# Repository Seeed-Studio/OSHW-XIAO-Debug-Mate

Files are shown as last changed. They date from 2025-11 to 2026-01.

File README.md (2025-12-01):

<p align="center">
  <h1 align="center">🔧 XIAO Debug Mate</h1>
  <p align="center">
    <strong>An Open-Source ESP32-S3 Multi-Tool for Embedded System Debugging</strong>
  </p>
  <p align="center">
    🐞 DAPLink Debugger | 📡 UART Monitor | ⚡ Power Profiler | 🖥️ Visual Feedback
  </p>
</p>

<p align="center">
  <a href="#-features">Features</a> •
  <a href="#-hardware">Hardware</a> •
  <a href="#-getting-started">Getting Started</a> •
  <a href="#-project-structure">Project Structure</a> •
  <a href="#-license">License</a>
</p>

<p align="center">
  <a href="https://www.seeedstudio.com/Seeed-Studio-XIAO-Debug-Mate-p-6588.html">
    
  </a>
  <a href="https://www.aliexpress.com/item/1005010448361665.html">
    
  </a>
  <a href="https://wiki.seeedstudio.com/getting_started_with_xiao_debug_mate/">
    
  </a>
</p>

<p align="center">
  
  
  
</p>

---

## 📖 Introduction

**Seeed Studio XIAO Debug Mate** is an open-source ESP32-S3 multi-tool that simplifies embedded system debugging with visual feedback. This all-in-one device features a standalone 2.01 inch TFT LCD display, LED status matrix, and native Seeed Studio XIAO support, delivering essential debugging functions: DAPLink chip-level debugging, built-in serial monitoring with UART passthrough, and accurate power consumption measurement. Plug-and-play design eliminates complex wiring for streamlined development.

## ✨ Features

### 🛠️ 3-in-1 Professional Development Tool

| Feature | Description |
|---|---|
| 🐞 **DAPLink-Compatible SWD Interface** | Powered by ESP32-S3 with full OpenOCD/PyOCD support, delivering professional-grade debugging capabilities. Set breakpoints, step through code, inspect memory, and access low-level hardware operations with precision. |
| 📡 **Intelligent Serial Monitor & UART Passthrough** | Monitor communications between your XIAO and the Debug Mate, or between the Debug Mate and external UART devices (Arduino, Raspberry Pi, Grove sensors). View real-time serial data on the onboard display or redirect to PC for detailed analysis. |
| ⚡ **Precision Power Profiling** | Track power consumption down to μA levels. Monitor voltage/current readings, ultra-low-power states, and consumption patterns with peak/valley identification. Factory-calibrated for maximum accuracy (±10% @ 1-10μA). |

### 🖥️ Standalone Visual Feedback System

Monitor key system metrics **without connecting to a PC**. The integrated 2.01" LCD screen displays real-time serial communications, power consumption readings, and UART data streams, while the programmable 36-LED matrix provides instant baud rate indicators. Perfect for on-site field testing, mobile development, and quick system power consumption checks.

### 🔌 Open-Source Platform with Universal Compatibility

Purpose-built for the **Seeed Studio XIAO ecosystem** with direct plug-and-play connection—any pre-soldered XIAO board connects instantly without tedious wiring. The thoughtfully designed pin headers and sockets transform the device into a specialized expansion breadboard for XIAO development. While optimized for XIAO, the open-source design extends compatibility to **any ARM Cortex-M microcontroller** via standard SWD and UART interfaces.

## 📋 Specifications

| Parameter | Description |
|---|---|
| **Processor** | Espressif ESP32-S3 |
| **Power Input** | USB-C 5V/1A |
| **Display** | 2.01 inch TFT LCD (240 × 296 resolution) |
| **LED** | 36-LED Matrix for Status Indication (Default: Baud Rate) |
| **User Input** | 1 × User Button/Boot Button, 1 × Scroll Wheel, 1 × Recessed Reset Button |
| **I/O Interface** | 14 × XIAO Standard Pins, 8 × Expansion Pins, 4 × SWD Debugging Pins, 1 × UART Grove Connector |
| **Product Size** | 100 × 56 × 20 mm |
| **Software** | Supports DAPLink for debugging |
| **Enclosure** | 3D-Printed in Black PLA |

## 🎯 Supported Target Boards

| Board | Interface | Status |
|---|---|---|
| 🟢 XIAO SAMD21 | SWD | ✅ Supported |
| 🟢 XIAO RA4M1 | SWD | ✅ Supported |
| 🟢 XIAO nRF52840 (Sense) | SWD | ✅ Supported |
| 🟢 XIAO RP2040 | SWD | ✅ Supported |
| 🟢 XIAO RP2350 | SWD | ✅ Supported |
| 🟢 XIAO MG24 (Sense) | SWD (OpenOCD) | ✅ Supported |

> ⚠️ **Note:** XIAO nRF54L15 and XIAO ESP32 series (C3/S3/C6) do **not** currently support debugging feature.

## 🚀 Getting Started

### ⚡ Quick Flash (Recommended for Users)

If you just want to use the XIAO Debug Mate, flash the pre-compiled firmware:

1. Install esptool: `pip install esptool`
2. Connect XIAO Debug Mate via USB-C
3. Enter download mode (hold BOOT, press RESET)
4. Run the flash script:

| OS | How to Run |
|----|---|
| 🍎 **macOS** | Open Terminal, navigate to `5_Release_firmware/`, run `./flash.sh` |
| 🐧 **Linux** | Open Terminal, navigate to `5_Release_firmware/`, run `./flash.sh` |
| 🪟 **Windows** | Double-click `flash.bat` |

```bash
# macOS / Linux
cd 5_Release_firmware
./flash.sh
```

> The script automatically detects and flashes the latest firmware version!

---

### 🛠️ Build from Source (For Developers)

#### Prerequisites

- **Arduino IDE** 2.x or later
- **ESP32 Board Support** (version 3.1.3, installed via Arduino Board Manager)
- **USB-C Cable** for programming

#### Quick Start

1️⃣ **Clone the Repository**
```bash
git clone https://github.com/Seeed-Studio/OSHW-XIAO-Debug-Mate.git
cd OSHW-XIAO-Debug-Mate
```

2️⃣ **Install Libraries**

Copy all libraries from `1_Libraries/` and the firmware library to your Arduino libraries folder:
```bash
# macOS / Linux
cp -r 1_Libraries/* ~/Documents/Arduino/libraries/
cp -r 0_Firmware ~/Documents/Arduino/libraries/Seeed_Debugger

# Windows
xcopy /E /I 1_Libraries\* "%USERPROFILE%\Documents\Arduino\libraries\"
xcopy /E /I 0_Firmware "%USERPROFILE%\Documents\Arduino\libraries\Seeed_Debugger"
```

> ⚠️ **Important:** The firmware must be installed as an Arduino library to compile correctly.

3️⃣ **Modify ESP32 Core Files**

> ⚠️ **Important:** You must modify the ESP32 Arduino core files to disable default USB initialization, otherwise TinyUSB will conflict with the default USB stack.

**Locate the ESP32 core files:**

| OS | Path |
|----|---|
| 🍎 **macOS** | `~/Library/Arduino15/packages/esp32/hardware/esp32/3.1.3/cores/esp32/` |
| 🪟 **Windows** | `%LOCALAPPDATA%\Arduino15\packages\esp32\hardware\esp32\3.1.3\cores\esp32\` |
| 🐧 **Linux** | `~/.arduino15/packages/esp32/hardware/esp32/3.1.3/cores/esp32/` |

**Modify the following 3 files:**

**File 1: `USB.cpp`** (around line 352)
```cpp
// Before:
ESPUSB USB;

// After:
// ESPUSB USB;
```

**File 2: `USB.h`** (around line 119)
```cpp
// Before:
extern ESPUSB USB;

// After:
// extern ESPUSB USB;
```

**File 3: `main.cpp`** (around lines 98 and 101)
```cpp
// Before:
#if ARDUINO_USB_DFU_ON_BOOT && !ARDUINO_USB_MODE
    USB.enableDFU();
#endif
#if ARDUINO_USB_ON_BOOT && !ARDUINO_USB_MODE
    USB.begin();
#endif

// After:
#if ARDUINO_USB_DFU_ON_BOOT && !ARDUINO_USB_MODE
    // USB.enableDFU();
#endif
#if ARDUINO_USB_ON_BOOT && !ARDUINO_USB_MODE
    // USB.begin();
#endif
```

4️⃣ **Configure Arduino IDE**

Set the following options in Arduino IDE:
- **Board**: "XIAO ESP32S3"
- **Partition Scheme**: "Maximum APP (7.9MB APP No OTA/No FS)"
- **PSRAM**: "OPI PSRAM"
- **USB Mode**: "USB-OTG (TinyUSB)"

5️⃣ **Upload Firmware**

- Go to **File → Examples → Seeed All-in-one Debugger → main**
- Or open `0_Firmware/examples/main/main.ino` directly
- Click **Upload**

## 📁 Project Structure

```
OSHW-XIAO-Debug-Mate/
├── 📂 0_Firmware/           # 🔧 Main firmware source code
│   ├── examples/            # Arduino sketch entry point
│   └── src/                 # Core library source files
│
├── 📂 1_Libraries/          # 📚 Required Arduino libraries
│   ├── Adafruit_BusIO/      # I2C/SPI communication
│   ├── Adafruit_INA228/     # Power monitoring sensor
│   ├── Adafruit_TinyUSB/    # USB device support
│   ├── lvgl_debug_mate/     # LVGL graphics library
│   ├── Seeed_Arduino_DAPLink/  # DAPLink implementation
│   ├── TFT_eSPI_Debug_Mate/ # TFT display driver
│   └── ...                  # Other supporting libraries
│
├── 📂 2_DAPLink_Package/    # 🎯 DAPLink tools and examples
│   ├── examples/            # Pre-compiled test binaries
│   ├── target/              # OpenOCD target configurations
│   └── XIAO_MG24_*/         # OpenOCD for MG24 debugging
│
├── 📂 3_Product_housing/    # 🏠 3D printable enclosure
│   └── *.stp, *.3mf         # CAD files for housing
│
├── 📂 4_Hardware/           # ⚡ Hardware documentation
│   └── *.pdf                # Schematic diagrams
│
└── 📂 5_Release_firmware/   # 📦 Pre-compiled firmware binaries
    ├── firmware-v*.bin      # Ready-to-flash firmware
    ├── flash.sh             # One-click flash (macOS/Linux)
    └── flash.bat            # One-click flash (Windows)
```

## 🖥️ User Interface

The XIAO Debug Mate features an intuitive menu system:

```
┌─────────────────────────────────┐
│         🏠 Main Menu            │
├─────────────────────────────────┤
│  📡  Function UART              │
│  ⚡  Function Power             │
└─────────────────────────────────┘
```

### Navigation
- **🔄 Scroll Wheel** - Navigate menu items
- **👆 Press** - Select/Confirm
- **👆 Long Press** - Back/Exit

## ⚙️ Configuration

### Baud Rate Options
The UART bridge supports multiple baud rates:
- 9600, 19200, 38400, 57600, 115200, 230400, 460800, 921600

### Power Monitoring
- **Accuracy**: ±10% @ 1-10μA (factory-calibrated)
- **Current Range**: μA to mA level precision
- **Features**: Peak/valley identification, real-time monitoring

## 🔗 Resources

- 🛒 [**Buy at Seeed Studio**](https://www.seeedstudio.com/Seeed-Studio-XIAO-Debug-Mate-p-6588.html)
- 🛒 [**Buy at AliExpress**](https://www.aliexpress.com/item/1005010448361665.html)
- 📖 [**Wiki Documentation**](https://wiki.seeedstudio.com/getting_started_with_xiao_debug_mate/)
- 💻 [**GitHub Repository**](https://github.com/Seeed-Studio/OSHW-XIAO-Debug-Mate)

## 🤝 Contributing

We welcome contributions! Please feel free to:

- 🐛 Report bugs
- 💡 Suggest new features
- 🔧 Submit pull requests
- 📖 Improve documentation

## 📄 License

This project is open-source hardware (OSHW). See individual library directories for their specific licenses.

## 🙏 Acknowledgments
This product started with a simple GitHub discussion back in July 2024, where one of our XIAO Core users [rei-vilo opened Discussion #20 in our XIAO Open Roadmap](https://github.com/orgs/Seeed-Studio/discussions/20) with an observation that resonated with many developers: “A programmer-debugger probe is a very useful and ‘must have’ tool for embedded system development. Today, there is no affordable offer.” Then we started the journey of creating this device together with many other community members who contributed a lot of input. Thank you to everyone who contributed ideas and feedback throughout this journey. A special big shout-out to [rei-vilo](https://github.com/rei-vilo), [Chris](https://github.com/CWGwaltney), PJ, Hendra, Ernesto, [Benjamin](https://github.com/kartben), [Pete](https://github.com/petejohanson), NitekryDPaul for insightful feedback during v0.1 testing.

- **Seeed Studio** - Hardware design and development
- **LVGL** - Graphics library
- **Adafruit** - Various Arduino libraries
- **ARM** - CMSIS-DAP protocol
- **[啊猫啊狗晒太阳](https://space.bilibili.com/1155738723)** - [Design inspiration](https://www.bilibili.com/video/BV1Sc411273Y/) for the LED matrix

---

<p align="center">
  Made with ❤️ by <a href="https://www.seeedstudio.com">Seeed Studio</a>
</p>

<p align="center">
  <sub>🌟 Star us on GitHub — it motivates us a lot!</sub>
</p>

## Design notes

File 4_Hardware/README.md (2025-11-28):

# ⚡ Hardware Documentation

This directory contains the hardware design documentation for the XIAO Debug Mate.

## 📁 Files Included

| File | Description |
|---|---|
| `Seeed_Studio_XIAO_Debug_Mate_V1.0_SCH_20250926.pdf` | Complete schematic diagram |

## 📋 Hardware Specifications

### Main Controller

| Parameter | Value |
|---|---|
| Module | Seeed Studio XIAO ESP32-S3 |
| MCU | ESP32-S3 (Xtensa LX7 dual-core) |
| Clock Speed | 240 MHz |
| Flash | 8 MB |
| PSRAM | 8 MB (OPI) |
| USB | Native USB OTG |

### Display

| Parameter | Value |
|---|---|
| Type | TFT LCD |
| Controller | ST7789 |
| Resolution | 240 × 320 pixels |
| Size | 2.0 inches |
| Interface | SPI |
| Color Depth | 16-bit (RGB565) |

### Power Monitor

| Parameter | Value |
|---|---|
| IC | Texas Instruments INA228 |
| Interface | I2C (Address: 0x43) |
| Voltage Range | 0-85V |
| Current Sense | External shunt |
| Shunt Resistor | 68mΩ |
| Max Current | 1A |
| Resolution | 20-bit ADC |

### Storage

| Parameter | Value |
|---|---|
| Type | I2C EEPROM |
| Interface | I2C (Address: 0x50) |
| Capacity | Varies by model |
| Purpose | Configuration storage |

### User Interface

| Component | Description |
|---|---|
| Rotary Encoder | Navigation input with push button |
| Status LEDs | Shift register controlled RGB LEDs |
| Boot Button | GPIO0 for mode selection |

## 🔌 Pinout Reference

### XIAO ESP32-S3 Pin Assignments

```
                    ┌─────────────┐
                    │  XIAO       │
                    │  ESP32-S3   │
         ┌──────────┤             ├──────────┐
         │          │             │          │
    D0 ──┤ GPIO1    │             │ GPIO44 ├── TX
    D1 ──┤ GPIO2    │             │ GPIO43 ├── RX
    D2 ──┤ GPIO3    │             │ GPIO7  ├── LED_CLK
    D3 ──┤ GPIO4    │             │ GPIO8  ├── LED_LATCH
    D4 ──┤ GPIO5    │             │ GPIO9  ├── LED_DATA
    D5 ──┤ GPIO6    │             │ GPIO17 ├── ENC_B
         │          │             │ GPIO18 ├── ENC_A
         │          │             │ GPIO48 ├── UART_SW
         │          │             │ GPIO0  ├── BOOT_BTN
         │          │             │ GPIO15 ├── MOS2
         │          │             │ GPIO16 ├── MOS1
         └──────────┤             ├──────────┘
                    │   USB-C     │
                    └─────────────┘
```

### I2C Bus Connections

| Device | SDA Pin | SCL Pin | Address | Speed |
|---|---|---|---|---|
| INA228 | GPIO4 | GPIO3 | 0x43 | 100kHz |
| EEPROM | GPIO1 | GPIO2 | 0x50 | 100kHz |

### LED Shift Register

| Pin | Function |
|-----|---|
| GPIO9 | Serial Data |
| GPIO7 | Clock |
| GPIO8 | Latch |

### Rotary Encoder

| Pin | Function |
|-----|---|
| GPIO18 | Channel A |
| GPIO17 | Channel B |
| GPIO0 | Push Button (shared with BOOT) |

### UART Bridge

| Pin | Function |
|-----|---|
| Serial0 RX | Target TX |
| Serial0 TX | Target RX |
| GPIO48 | UART Switch Control |

## 📊 Block Diagram

```
┌─────────────────────────────────────────────────────────────────┐
│                      XIAO Debug Mate                            │
│                                                                 │
│  ┌─────────────┐     ┌─────────────┐     ┌─────────────┐       │
│  │   XIAO      │     │   ST7789    │     │   INA228    │       │
│  │  ESP32-S3   │────▶│   Display   │     │  Power Mon  │       │
│  │             │     │  240×320    │     │             │       │
│  │   USB-OTG   │     └─────────────┘     └──────┬──────┘       │
│  └──────┬──────┘                                │              │
│         │         ┌─────────────┐               │              │
│         │         │   I2C       │◀──────────────┘              │
│         │         │   EEPROM    │                              │
│         │         └─────────────┘                              │
│         │                                                       │
│         │         ┌─────────────┐     ┌─────────────┐          │
│         │         │   Shift     │     │   Rotary    │          │
│         └────────▶│   Register  │     │   Encoder   │          │
│                   │   (LEDs)    │     │             │          │
│                   └─────────────┘     └─────────────┘          │
│                                                                 │
│  ┌─────────────────────────────────────────────────────────┐   │
│  │                   Debug Connector                        │   │
│  │   SWDIO  SWCLK  GND  3V3  RST  TX  RX                   │   │
│  └─────────────────────────────────────────────────────────┘   │
└─────────────────────────────────────────────────────────────────┘
```

## ⚡ Power Architecture

```
USB 5V ──┬──▶ XIAO 3.3V LDO ──▶ Internal Logic
         │
         └──▶ Power Output ──▶ Target Device (optional)
                    │
                    └──▶ INA228 Current Sense ──▶ Measurement
```

### Power Specifications

| Parameter | Min | Typical | Max | Unit |
|---|-----|---|-----|---|
| Input Voltage (USB) | 4.5 | 5.0 | 5.5 | V |
| Operating Current | - | 100 | 250 | mA |
| Target Power Output | - | 3.3 | - | V |
| Target Current Limit | - | - | 500 | mA |

## 🔧 Debug Interface

### SWD Connector Pinout

| Pin | Signal | Description |
|-----|---|---|
| 1 | VCC | Target power (3.3V) |
| 2 | SWDIO | Serial Wire Data |
| 3 | SWCLK | Serial Wire Clock |
| 4 | GND | Ground |
| 5 | RST | Target Reset |

### UART Header Pinout

| Pin | Signal | Description |
|-----|---|---|
| 1 | TX | Transmit (to target RX) |
| 2 | RX | Receive (from target TX) |
| 3 | GND | Ground |

## 📐 Mechanical Dimensions

| Parameter | Value |
|---|---|
| PCB Length | ~90 mm |
| PCB Width | ~50 mm |
| Overall Height | ~25 mm (with housing) |

## 🛠️ Design Files

The schematic PDF provides:
- Complete circuit topology
- Component values and part numbers
- Net names for debugging
- Power distribution network

### Reading the Schematic

1. **Power Section** - USB input, regulators, power distribution
2. **MCU Section** - XIAO ESP32-S3 connections
3. **Display Section** - TFT interface and backlight
4. **Sensor Section** - INA228 and EEPROM
5. **Interface Section** - Debug connector and UART
6. **LED Section** - Shift register and status LEDs

## ⚠️ Design Considerations

### EMI/EMC
- Keep SWD traces short and matched
- Use ground plane under high-speed signals
- Add ferrite beads on power inputs

### Signal Integrity
- Maintain controlled impedance for SPI signals
- Use series termination resistors where needed
- Minimize crosstalk between analog and digital

### Thermal
- Ensure adequate copper pour for heat dissipation
- Consider airflow in enclosure design
- Monitor operating temperature during extended use

## 📚 References

- [ESP32-S3 Technical Reference Manual](https://www.espressif.com/sites/default/files/documentation/esp32-s3_technical_reference_manual_en.pdf)
- [INA228 Datasheet](https://www.ti.com/lit/ds/symlink/ina228.pdf)
- [ST7789 Datasheet](https://www.crystalfontz.com/controllers/Sitronix/ST7789V/)
- [CMSIS-DAP Specification](https://arm-software.github.io/CMSIS_5/DAP/html/index.html)

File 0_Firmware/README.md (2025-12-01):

# 🔧 XIAO Debug Mate Firmware

This directory contains the main firmware source code for the XIAO Debug Mate. The firmware is structured as an **Arduino Library** and must be installed in your Arduino libraries folder to use.

## 📦 Installation

### Method 1: Copy to Arduino Libraries (Recommended)

Copy the entire `0_Firmware` folder to your Arduino libraries directory and rename it:

```bash
# macOS
cp -r 0_Firmware ~/Documents/Arduino/libraries/Seeed_Debugger

# Windows
xcopy /E /I 0_Firmware "%USERPROFILE%\Documents\Arduino\libraries\Seeed_Debugger"

# Linux
cp -r 0_Firmware ~/Arduino/libraries/Seeed_Debugger
```

### Method 2: Symbolic Link (For Development)

Create a symbolic link if you want to develop and modify the firmware:

```bash
# macOS / Linux
ln -s "$(pwd)/0_Firmware" ~/Documents/Arduino/libraries/Seeed_Debugger

# Windows (Run as Administrator)
mklink /D "%USERPROFILE%\Documents\Arduino\libraries\Seeed_Debugger" "%cd%\0_Firmware"
```

## 📁 Directory Structure

```
0_Firmware/
├── examples/
│   └── main/
│       └── main.ino      # Main Arduino sketch entry point
├── src/                  # Core library source files
│   ├── DapLink.*         # DAPLink debugger implementation
│   ├── StateMachine.*    # State machine framework
│   ├── StateManager.*    # State management
│   ├── MenuStates.*      # Main menu UI states
│   ├── FunctionUartState.*   # UART bridge function
│   ├── FunctionBaudState.*   # Baud rate configuration
│   ├── FunctionPowerState.*  # Power monitoring function
│   ├── InputTask.*       # Scroll wheel and button input handling
│   ├── DisplayContext.*  # Display management
│   ├── LvglStyle.*       # LVGL UI styling
│   ├── Tool.*            # Utility functions
│   ├── frame.*           # Boot animation frames
│   └── ...
├── library.properties    # Arduino library metadata
└── keywords.txt          # Syntax highlighting keywords
```

## 🚀 Getting Started

### Prerequisites

1. **Arduino IDE 2.x** or later
2. **ESP32 Board Package** version 3.1.3 installed via Board Manager
3. All libraries from `1_Libraries/` installed (see [1_Libraries/README.md](../1_Libraries/README.md))
4. This firmware library installed (see Installation above)

### Step 1: Install Required Libraries

Copy all libraries from `1_Libraries/` to your Arduino libraries folder:

```bash
# macOS
cp -r ../1_Libraries/* ~/Documents/Arduino/libraries/

# Windows
xcopy /E /I ..\1_Libraries\* "%USERPROFILE%\Documents\Arduino\libraries\"

# Linux
cp -r ../1_Libraries/* ~/Arduino/libraries/
```

### Step 2: Modify ESP32 Core Files

> ⚠️ **Important:** You must modify the ESP32 Arduino core files to disable default USB initialization, otherwise TinyUSB will conflict with the default USB stack.

**Locate the ESP32 core files:**

| OS | Path |
|----|---|
| 🍎 **macOS** | `~/Library/Arduino15/packages/esp32/hardware/esp32/3.1.3/cores/esp32/` |
| 🪟 **Windows** | `%LOCALAPPDATA%\Arduino15\packages\esp32\hardware\esp32\3.1.3\cores\esp32\` |
| 🐧 **Linux** | `~/.arduino15/packages/esp32/hardware/esp32/3.1.3/cores/esp32/` |

**Modify the following 3 files:**

#### File 1: `USB.cpp` (around line 352)
```cpp
// Before:
ESPUSB USB;

// After:
// ESPUSB USB;
```

#### File 2: `USB.h` (around line 119)
```cpp
// Before:
extern ESPUSB USB;

// After:
// extern ESPUSB USB;
```

#### File 3: `main.cpp` (around lines 98 and 101)
```cpp
// Before:
#if ARDUINO_USB_DFU_ON_BOOT && !ARDUINO_USB_MODE
    USB.enableDFU();
#endif
#if ARDUINO_USB_ON_BOOT && !ARDUINO_USB_MODE
    USB.begin();
#endif

// After:
#if ARDUINO_USB_DFU_ON_BOOT && !ARDUINO_USB_MODE
    // USB.enableDFU();
#endif
#if ARDUINO_USB_ON_BOOT && !ARDUINO_USB_MODE
    // USB.begin();
#endif
```

### Step 3: Configure Arduino IDE

Configure the following settings in Arduino IDE:

| Setting | Value |
|---|---|
| **Board** | XIAO ESP32S3 |
| **Partition Scheme** | Maximum APP (7.9MB APP No OTA/No FS) |
| **PSRAM** | OPI PSRAM |
| **USB Mode** | USB-OTG (TinyUSB) |

### Step 4: Open and Upload

1. In Arduino IDE, go to **File → Examples → Seeed All-in-one Debugger → main**
2. Or open `examples/main/main.ino` directly
3. Select the correct port (your XIAO Debug Mate)
4. Click **Upload**

> 💡 **Tip:** If the device is not detected, enter Boot Mode by holding BOOT button while pressing RESET.

## 🏗️ Architecture

The firmware uses a **State Machine** architecture for managing different operational modes:

```
┌─────────────────┐
│   Main Menu     │◄────────────────┐
└────────┬────────┘                 │
         │                          │
    ┌────┴────┐                     │
    ▼         ▼                     │
┌───────┐ ┌───────┐                 │
│ UART  │ │ Power │──── Back ───────┤
│ Mode  │ │ Mode  │                 │
└───┬───┘ └───────┘                 │
    │                               │
    ▼                               │
┌───────┐                           │
│ Baud  │──── Back ─────────────────┘
│ Rate  │
└───────┘
```

## 📦 Core Components

### State Machine (`StateMachine.*`)
- Manages application states and transitions
- Handles state initialization and cleanup
- Provides error state fallback

### Input Task (`InputTask.*`)
- Handles scroll wheel rotation
- Debounces button presses
- Detects long press events
- Sends events to state machine via FreeRTOS queue

### Display Context (`DisplayContext.*`)
- Manages LVGL display operations
- Controls 36-LED status matrix
- Interfaces with INA228 power monitor

### DAPLink (`DapLink.*`)
- Implements CMSIS-DAP protocol
- Provides SWD debugging interface
- Handles USB HID communication

## 🔧 Key Functions

### Main Menu Functions

| Function | Description |
|---|---|
| **UART Mode** | Serial monitor & UART passthrough |
| **Power Mode** | Precision power profiling (μA level) |

### UART Mode Features
- Configurable baud rate (9600 - 921600)
- Real-time TX/RX data visualization on display
- 36-LED matrix shows current baud rate

### Power Mode Features
- Real-time voltage/current display
- μA level precision (factory-calibrated)
- Peak/valley identification

## ⚙️ Configuration

### Hardware Pins (defined in `Global.h`)

```cpp
#define BOOT_BTN 0
#define ENCODER_PINA 18
#define ENCODER_PINB 17
#define UART_SWITCH 48
#define LED_DATA 9
#define LED_CLOCK 7
#define LED_LATCH 8
```

### Display Settings

```cpp
#define TFT_HOR_RES   240
#define TFT_VER_RES   296
#define TFT_ROTATION  LV_DISPLAY_ROTATION_90
```

## 🐛 Debugging

Serial debug output is available at the configured baud rate:

```cpp
ShowSerial.begin(FunctionBaudState::m_baudRate);
```

Debug messages can be viewed via the Arduino Serial Monitor.

## 📝 Adding New States

To add a new function state:

1. Create new state files (e.g., `NewFunctionState.h/.cpp`) in the `src/` folder
2. Inherit from `State` base class
3. Implement required virtual methods:
   - `enter()` - Called when entering state
   - `exit()` - Called when leaving state
   - `handleEvent()` - Process user input events
4. Register state in `main.ino`:
   ```cpp
   NewFunctionState* newState = new NewFunctionState();
   stateManager->registerState(newState);
   ```
5. Add menu item in MainMenuState

## ⚠️ Troubleshooting

### Library Not Found

If Arduino IDE can't find the library:
1. Make sure the folder is named correctly in the libraries directory
2. Restart Arduino IDE after installing
3. Check **File → Examples** to see if "Seeed All-in-one Debugger" appears

### Compilation Errors

1. Ensure all dependencies from `1_Libraries/` are installed
2. Check that ESP32 board package version is 3.1.3
3. Verify Arduino IDE settings match the table above
4. **If you see USB-related errors:** Make sure you've modified the ESP32 core files (see Step 2)

### USB Conflict / TinyUSB Not Working

If DAPLink or USB functionality doesn't work:
1. Verify you've commented out the USB initialization in the ESP32 core files
2. Make sure you modified all 3 files: `USB.cpp`, `USB.h`, and `main.cpp`
3. Restart Arduino IDE after modifying core files

### Upload Failed

1. Enter Boot Mode: Hold BOOT → Press RESET → Release BOOT
2. Select the correct COM port
3. Try a different USB cable (use data cable, not charge-only)

## 📄 License

Part of the XIAO Debug Mate open-source hardware project by Seeed Studio.

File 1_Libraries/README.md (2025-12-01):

# 📚 Required Libraries

This directory contains all the Arduino libraries required for the XIAO Debug Mate firmware.

## 📦 Installation

### Option 1: Use Pre-packaged Libraries (Recommended)

Copy all contents of this directory to your Arduino libraries folder:

```bash
# macOS
cp -r * ~/Documents/Arduino/libraries/

# Windows
xcopy /E /I * "%USERPROFILE%\Documents\Arduino\libraries\"

# Linux
cp -r * ~/Arduino/libraries/
```

### Option 2: Install from Source

#### Step 1: Install from Arduino Library Manager

Open Arduino IDE → **Sketch → Include Library → Manage Libraries**, then install:

| Library | Recommended Version |
|---|---|
| **Adafruit INA228 Library** | 2.0.1 |
| **Adafruit TinyUSB Library** | 3.4.4 |

#### Step 2: Clone Custom Libraries

These libraries require specific branches. Open terminal and run:

```bash
# Go to the library directory
cd ~/Documents/Arduino/libraries

# DAPLink (custom ESP32-S3 branch)
git clone --depth 1 https://github.com/Lesords/Seeed_Arduino_DAPLink.git -b feat/ESP32S3

# TFT (custom ST7789-EVT branch)
git clone --depth 1 https://github.com/Lesords/TFT_eSPI.git -b feat/ST7789-EVT

# LVGL (custom Debugger branch)
git clone --depth 1 https://github.com/Lesords/lvgl.git -b feat/Debugger
```

## 📋 Library Overview

| Library | Version / Branch | Source | Description |
|---|---|---|---|
| **Seeed_Arduino_DAPLink** | `feat/ESP32S3` | [Lesords/Seeed_Arduino_DAPLink](https://github.com/Lesords/Seeed_Arduino_DAPLink/tree/feat/ESP32S3) | CMSIS-DAP debugger (ESP32-S3 fork) |
| **TFT_eSPI** | `feat/ST7789-EVT` | [Lesords/TFT_eSPI](https://github.com/Lesords/TFT_eSPI/tree/feat/ST7789-EVT) | TFT display driver (custom fork) |
| **lvgl** | `feat/Debugger` | [Lesords/lvgl](https://github.com/Lesords/lvgl/tree/feat/Debugger) | LVGL graphics library (custom fork) |
| **Adafruit_INA228** | 2.0.1 | [adafruit/Adafruit_INA228](https://github.com/adafruit/Adafruit_INA228) | Power monitor driver |
| **Adafruit_TinyUSB** | 3.4.4 | [adafruit/Adafruit_TinyUSB_Arduino](https://github.com/adafruit/Adafruit_TinyUSB_Arduino) | USB device stack |
| **Adafruit_BusIO** | 1.17.4 | [adafruit/Adafruit_BusIO](https://github.com/adafruit/Adafruit_BusIO) | I2C/SPI abstraction layer |
| **I2C_EEPROM** | 1.9.4 | [RobTillaart/I2C_EEPROM](https://github.com/RobTillaart/I2C_EEPROM) | I2C EEPROM library |
| **Adafruit_NeoPixel** | 1.3.3 | [adafruit/Adafruit_NeoPixel](https://github.com/adafruit/Adafruit_NeoPixel) | RGB LED driver |
| **Adafruit_SPIFlash** | 5.1.1 | [adafruit/Adafruit_SPIFlash](https://github.com/adafruit/Adafruit_SPIFlash) | SPI Flash support |
| **SdFat** | 2.3.54 | [adafruit/SdFat](https://github.com/adafruit/SdFat) | SD card FAT filesystem |
| **MIDI_Library** | 5.0.2 | [FortySevenEffects/arduino_midi_library](https://github.com/FortySevenEffects/arduino_midi_library) | MIDI communication |

## ⚠️ Important: Custom Library Branches

The following libraries **must** use specific custom branches to work with XIAO Debug Mate:

| Library | Required Branch | Why |
|---|---|-----|
| **Seeed_Arduino_DAPLink** | `feat/ESP32S3` | ESP32-S3 specific implementation |
| **TFT_eSPI** | `feat/ST7789-EVT` | Pre-configured for Debug Mate display |
| **lvgl** | `feat/Debugger` | Custom UI components and boot animation |

> ⚠️ Using the original/main branches will **not** work!

## 🔍 Library Details

### 🐞 Seeed_Arduino_DAPLink

Custom fork with ESP32-S3 support for CMSIS-DAP debugging.

**Branch:** `feat/ESP32S3`  
**Source:** https://github.com/Lesords/Seeed_Arduino_DAPLink

**Supported Protocols:**
- SWD (Serial Wire Debug)

**Supported Targets:**
- ARM Cortex-M0/M0+
- ARM Cortex-M3/M4
- ARM Cortex-M33

### 🖥️ TFT_eSPI

Custom fork optimized for the XIAO Debug Mate display.

**Branch:** `feat/ST7789-EVT`  
**Source:** https://github.com/Lesords/TFT_eSPI

**Features:**
- ST7789 driver support (240×296 resolution)
- Hardware SPI acceleration
- LVGL integration ready
- Pre-configured `User_Setup.h`

### 🎨 lvgl (LVGL Debug Mate)

LVGL (Light and Versatile Graphics Library) customized for Debug Mate.

**Branch:** `feat/Debugger`  
**Source:** https://github.com/Lesords/lvgl

**Features:**
- Animated boot screen
- Menu system widgets
- Power monitoring display
- Custom fonts and styles

**Configuration:** Settings in `lv_conf.h`

### ⚡ Adafruit_INA228

Driver for the INA228 high-precision power monitor IC.

**Version:** 2.0.1 (from Arduino Library Manager)  
**Source:** https://github.com/adafruit/Adafruit_INA228

**Capabilities:**
- Voltage measurement: 0-85V
- Current measurement (with external shunt)
- Power calculation
- Energy accumulation

**Debug Mate Config:**
```cpp
ina228.setShunt(0.068, 1.0);  // 68mΩ shunt, 1A max
ina228.setAveragingCount(INA228_COUNT_16);
```

### 🔌 Adafruit_TinyUSB

USB device stack enabling USB functionality.

**Version:** 3.4.4 (from Arduino Library Manager)  
**Source:** https://github.com/adafruit/Adafruit_TinyUSB_Arduino

**Features Used:**
- USB CDC (Serial)
- USB HID (for DAPLink)
- Composite USB device

### 💾 I2C_EEPROM

Library for reading/writing I2C EEPROM chips.

**Version:** 1.9.4  
**Source:** https://github.com/RobTillaart/I2C_EEPROM

**Usage:**
- Store user settings
- Persist baud rate configuration
- Save calibration data

## ⚙️ Configuration Files

### `lv_conf.h`

Main LVGL configuration file. Key settings:

```c
#define LV_COLOR_DEPTH 16
#define LV_MEM_SIZE (48 * 1024)
#define LV_USE_ANIMIMG 1
#define LV_FONT_MONTSERRAT_14 1
```

## 🛠️ Troubleshooting

### Library Not Found Error
Make sure all libraries are copied to the correct Arduino libraries folder.

### Compilation Errors
1. Ensure you're using the correct custom branches (not main/master)
2. Remove any duplicate libraries from your Arduino libraries folder
3. Restart Arduino IDE after installing libraries

### Display Not Working
Check that you're using `TFT_eSPI` from the `feat/ST7789-EVT` branch, not the standard library.

### DAPLink Not Working
Ensure you're using `Seeed_Arduino_DAPLink` from the `feat/ESP32S3` branch.

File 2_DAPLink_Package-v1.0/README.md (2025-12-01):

# 🎯 DAPLink Package v1.0

This directory contains pre-compiled example binaries, target configurations, and OpenOCD tools for debugging various XIAO boards with the XIAO Debug Mate.

## 📖 Documentation

For complete usage instructions, please refer to the official Wiki:

👉 **[DAPLink Debugger Wiki](https://wiki.seeedstudio.com/xiao_debug_mate_debug/)**

The Wiki provides comprehensive guides on:
- Understanding debugger concepts (GDB, OpenOCD, PyOCD, CMSIS-DAP)
- Step-by-step debugging tutorials
- Flashing firmware using OpenOCD/PyOCD
- Using debugging with PlatformIO
- Troubleshooting common issues

## 📁 Directory Structure

```
2_DAPLink_Package-v1.0/
├── examples/                    # Pre-compiled test binaries
│   ├── Blink_*.bin/hex         # Blink examples for each target
│   └── Bootloader_*.bin/hex    # Bootloader files
├── target/                      # OpenOCD target configurations
│   ├── XIAO_RA4M1/             # Renesas RA4M1 config
│   └── XIAO_SAMD21/            # Microchip SAMD21 config
├── XIAO_MG24_Mac_Linux_OpenOCD-v0.12.0/  # OpenOCD for Mac/Linux
└── XIAO_MG24_Win_OpenOCD-v0.12.0/        # OpenOCD for Windows
```

## 🎯 Compatibility

| XIAO Model | DAPLink Debug | UART Monitor | Power Analyzer |
|---|---|---|---|
| XIAO SAMD21 | ✅ | ✅ | ✅ |
| XIAO RA4M1 | ✅ | ✅ | ✅ |
| XIAO nRF52840 (Sense) | ✅ | ✅ | ✅ |
| XIAO RP2040 | ✅ | ✅ | ✅ |
| XIAO RP2350 | ✅ | ✅ | ✅ |
| XIAO MG24 (Sense) | ✅ | ✅ | ✅ |
| XIAO nRF54L15 | ❌ | ✅ | ✅ |
| XIAO ESP32C3/S3/C6 | ❌ | ✅ | ✅ |

> ⚠️ **Note:** DAPLink debugging only works with ARM Cortex-M cores. XIAO nRF54L15 and ESP32 series do not support DAPLink debugging.

## 🔧 Pre-compiled Examples

Test binaries to verify your debugging setup:

| File | Target Board | Description |
|---|---|---|
| `Blink_SAMD21.bin/.hex` | XIAO SAMD21 | LED blink test |
| `Blink_RA4M1.bin/.hex` | XIAO RA4M1 | LED blink test |
| `Blink_nRF52840.bin/.hex/.elf` | XIAO nRF52840 | LED blink test |
| `Blink_RP2040.bin/.elf` | XIAO RP2040 | LED blink test |
| `Blink_RP2350.bin/.elf` | XIAO RP2350 | LED blink test |
| `Blink_MG24.hex` | XIAO MG24 | LED blink test |
| `Bootloader_SAMD21.bin` | XIAO SAMD21 | UF2 bootloader |
| `Bootloader_RA4M1.hex` | XIAO RA4M1 | Bootloader |
| `Bootloader_nRF52840-0.6.1.hex` | XIAO nRF52840 | Adafruit bootloader |

## 🎯 Target Configurations

### XIAO SAMD21
- **File:** `target/XIAO_SAMD21/at91samd21g18.cfg`
- **MCU:** Microchip ATSAMD21G18A
- **Core:** ARM Cortex-M0+

### XIAO RA4M1
- **File:** `target/XIAO_RA4M1/ra4m1.cfg`
- **MCU:** Renesas R7FA4M1AB
- **Core:** ARM Cortex-M4

## 🚀 Quick Start

### Install Required Tools

```bash
# Install OpenOCD (recommended: xpack-openocd 0.12.0)
# Or use the bundled OpenOCD in XIAO_MG24_*/

# Install PyOCD (alternative)
pip install pyocd
```

### Flash Firmware Example

```bash
# Using OpenOCD
openocd -f interface/cmsis-dap.cfg -f target/at91samd21g18.cfg \
  -c "program examples/Blink_SAMD21.hex verify reset exit"

# Using PyOCD
pyocd flash -t atsamd21g18a examples/Blink_SAMD21.hex
```

## 📚 Resources

- 📖 [DAPLink Debugger Wiki](https://wiki.seeedstudio.com/xiao_debug_mate_debug/)
- 📖 [UART Monitor Wiki](https://wiki.seeedstudio.com/xiao_debug_mate_uart/)
- 📖 [Power Meter Wiki](https://wiki.seeedstudio.com/xiao_debug_mate_power/)
- 🔗 [ARM CMSIS-DAP Documentation](https://arm-software.github.io/CMSIS_5/DAP/html/index.html)
- 🔗 [OpenOCD User Manual](https://openocd.org/doc/html/index.html)
- 🔗 [PyOCD Documentation](https://pyocd.io/)

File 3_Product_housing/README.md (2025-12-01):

# 🏠 Product Housing

This directory contains 3D printable enclosure files for the XIAO Debug Mate.

## 📁 Files Included

| File | Description | Dimensions |
|---|---|---|
| `Debugger Upper Housing` | Top shell of the enclosure | 100 × 57 × 11 mm |
| `Debugger Lower Housing` | Bottom shell of the enclosure | 100 × 58 × 12.2 mm |
| `Debugger Screen Mounting Block` | TFT display mount bracket | 57.5 × 47.5 × 6.4 mm |
| `Debugger Keycap` | Rotary encoder button cap | 16.8 × 6.4 × 5 mm |
| `Bambu_Studio_XIAO_Debug_Mate.3mf` | Pre-configured Bambu Studio project |

## 🖨️ Printing Recommendations

### Material
- **Recommended:** PLA

### Color Scheme
| Part | Recommended Color |
|---|---|
| Upper Housing | Black |
| Lower Housing | Black |
| Screen Mount | Black |
| Keycap | Green (for visibility) |

### Print Settings

| Parameter | Value |
|---|---|
| Layer Height | 0.2 mm |
| Infill | 20-30% |
| Wall Loops | 3 |
| Top/Bottom Layers | 4 |
| Supports | Yes (for housing parts) |

### Orientation Guide

```
Upper Housing:
  └── Print with the outer surface facing up
      (supports needed for internal features)

Lower Housing:
  └── Print with the outer surface facing down
      (supports needed for screw posts)

Screen Mount:
  └── Print flat on the build plate
      (minimal supports needed)

Keycap:
  └── Print with the top surface facing up
      (no supports needed)
```

## 🔧 Post-Processing

### Required Steps

1. **Remove Supports**
   - Carefully remove all support material
   - Use pliers for hard-to-reach areas

2. **Deburring**
   - Remove any sharp edges or protrusions
   - Sand connection points for smooth fit
   - Focus on areas where parts mate together

3. **Test Fit**
   - Verify PCB fits in lower housing
   - Check screen alignment with mount
   - Ensure buttons operate freely

### Optional Finishing

- **Sanding:** 220-400 grit for smooth surface
- **Acetone Vapor Smoothing:** For ABS parts only
- **Paint:** Acrylic or spray paint for custom colors

## 📐 Assembly Order

```
1. Install screen in mounting block
         │
         ▼
2. Mount PCB in lower housing
         │
         ▼
3. Attach screen assembly
         │
         ▼
4. Place keycap on encoder
         │
         ▼
5. Close with upper housing
         │
         ▼
6. Secure with screws
```

## 🔩 Hardware Required

| Item | Quantity | Specification |
|---|---|---|
| Self-tapping screws | 4 | M2 × 6mm |
| Screen mounting screws | 4 | M2 × 4mm |

## 📦 Using Bambu Studio

The included `.3mf` file contains pre-configured settings:

1. Open `Bambu_Studio_XIAO_Debug_Mate.3mf` in Bambu Studio
2. Select your printer profile
3. Adjust settings if needed
4. Slice and print

**Note:** Settings are optimized for Bambu Lab printers but can be adapted for other printers.

## 🎨 Customization

The STEP (.stp) files can be modified in CAD software:

- **Fusion 360** - Import STEP, modify, export STL
- **SolidWorks** - Open STEP directly
- **FreeCAD** - Import STEP (open-source option)
- **Onshape** - Import STEP (browser-based)

### Common Modifications

- Add ventilation holes
- Customize button height
- Add mounting points
- Engrave logo or text

## ⚠️ Important Notes

1. **Tolerances:** Printed parts may need slight adjustment for fit
2. **Shrinkage:** ABS shrinks ~0.5-0.8% - account for this if modifying
3. **Heat:** Ensure adequate ventilation; electronics generate heat during operation
4. **Connectors:** Verify USB-C and debug connector clearances after printing

## 📸 Preview

```
     ┌────────────────────────────┐
     │    ╔══════════════════╗    │
     │    ║                  ║    │
     │    ║    TFT Display   ║    │
     │    ║                  ║    │
     │    ╚══════════════════╝    │
     │                        ○   │  ← Keycap
     │   ○  USB-C      Debug ○   │
     └────────────────────────────┘
          XIAO Debug Mate
```

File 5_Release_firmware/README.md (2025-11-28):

# 📦 Release Firmware

This directory contains pre-compiled firmware binaries for the XIAO Debug Mate.

## 📋 Available Versions

| Version | File | Size | Release Date | Status |
|---|---|---|---|---|
| **v1.1** | `firmware-v1.1.bin` | 5.2 MB | 2025 | ✅ **Latest** |
| v1.0 | `firmware-v1.0.bin` | 8.0 MB | 2025 | Factory Version |

## 🚀 Quick Flash

### One-Click Flash (Recommended)

Run the flash script for your operating system:

| OS | Script | How to Run |
|----|---|---|
| 🍎 **macOS** | `flash.sh` | Open Terminal → `cd` to this folder → run `./flash.sh` |
| 🐧 **Linux** | `flash.sh` | Open Terminal → `cd` to this folder → run `./flash.sh` |
| 🪟 **Windows** | `flash.bat` | Double-click the file |

**macOS / Linux:**
```bash
cd /path/to/5_Release_firmware
./flash.sh
```

**Windows:**
Simply double-click `flash.bat`

> **Note:** The scripts automatically detect and flash the newest firmware version in the folder.

### Prerequisites

1. **Install esptool**
   ```bash
   pip install esptool
   ```

2. **Connect XIAO Debug Mate via USB-C**

3. **Enter Download Mode** (if needed)
   - Hold the BOOT button
   - Press and release the RESET button
   - Release the BOOT button

### Manual Flash

If you prefer to flash manually or need a specific version:

```bash
# macOS (replace /dev/cu.usbmodemXXXX with your actual port)
esptool.py --chip esp32s3 --port /dev/cu.usbmodem1301 --baud 921600 \
  --before default_reset --after hard_reset write_flash -z \
  --flash_mode keep --flash_freq keep --flash_size keep \
  0x10000 firmware-v1.1.bin

# Linux
esptool.py --chip esp32s3 --port /dev/ttyACM0 --baud 921600 \
  --before default_reset --after hard_reset write_flash -z \
  --flash_mode keep --flash_freq keep --flash_size keep \
  0x10000 firmware-v1.1.bin

# Windows (replace COM3 with your actual port)
esptool.exe --chip esp32s3 --port COM3 --baud 921600 ^
  --before default_reset --after hard_reset write_flash -z ^
  --flash_mode keep --flash_freq keep --flash_size keep ^
  0x10000 firmware-v1.1.bin
```

### Advanced Options

```bash
# Find your port
# macOS:
ls /dev/cu.usb*

# Linux:
ls /dev/ttyUSB* /dev/ttyACM*

# Erase flash before writing (use if having issues)
esptool.py --chip esp32s3 erase_flash

# Verify after writing
esptool.py --chip esp32s3 --port /dev/cu.usbmodem1301 --baud 921600 \
  --before default_reset --after hard_reset write_flash -z --verify \
  --flash_mode keep --flash_freq keep --flash_size keep \
  0x10000 firmware-v1.1.bin
```

---

## 📝 Release Notes

### 🆕 Version 1.1 (Latest)

**Release Highlights:**
- 🎨 **Redesigned Display UI** - Improved visual layout and user experience
- 🐛 **Bug Fixes** - Resolved display ghosting issues

**Detailed Changes:**

| Category | Description |
|---|---|
| 🖥️ Display | Completely redesigned display page layout |
| 🖥️ Display | Optimized screen refresh mechanism |
| 🐛 Bug Fix | Fixed display ghosting/artifacts that occurred in certain scenarios |
| 🐛 Bug Fix | Improved screen transition smoothness |
| ⚡ Performance | Reduced firmware size from 8.0MB to 5.2MB |

**Known Issues:**
- None reported

---

### 📦 Version 1.0 (Factory)

**Initial Release**

This is the factory firmware that ships with the XIAO Debug Mate.

**Features:**
- ✅ DAPLink debugger functionality
- ✅ UART bridge with configurable baud rate
- ✅ Real-time power monitoring
- ✅ LVGL-based graphical user interface
- ✅ Rotary encoder navigation
- ✅ Boot animation

**Known Issues:**
- ⚠️ Display ghosting may occur in some scenarios (fixed in v1.1)

---

## ⚠️ Troubleshooting

### Port Not Found

**macOS:**
```bash
ls /dev/cu.usb*
```

**Linux:**
```bash
ls /dev/ttyUSB* /dev/ttyACM*
```

**Windows:**
Check Device Manager for COM port number.

### Permission Denied (Linux)

```bash
sudo usermod -a -G dialout $USER
# Log out and log back in
```

### Device Not in Download Mode

1. Disconnect USB
2. Hold BOOT button
3. Connect USB while holding BOOT
4. Release BOOT button
5. Run flash script

### Flash Failed

1. Try a different USB cable (use data cable, not charge-only)
2. Try a different USB port
3. Reduce baud rate:
   ```bash
   esptool.py --chip esp32s3 --baud 115200 \
     --before default_reset --after hard_reset write_flash -z \
     --flash_mode keep --flash_freq keep --flash_size keep \
     0x10000 firmware-v1.1.bin
   ```

## 🔄 Downgrade

To downgrade to a previous version, simply flash the older firmware:

```bash
esptool.py --chip esp32s3 --baud 921600 \
  --before default_reset --after hard_reset write_flash -z \
  --flash_mode keep --flash_freq keep --flash_size keep \
  0x10000 firmware-v1.0.bin
```

## 📊 Firmware Comparison

| Feature | v1.0 | v1.1 |
|---|---|---|
| DAPLink | ✅ | ✅ |
| UART Bridge | ✅ | ✅ |
| Power Monitor | ✅ | ✅ |
| Display UI | Basic | ✨ Improved |
| Ghosting Fix | ❌ | ✅ |
| File Size | 8.0 MB | 5.2 MB |

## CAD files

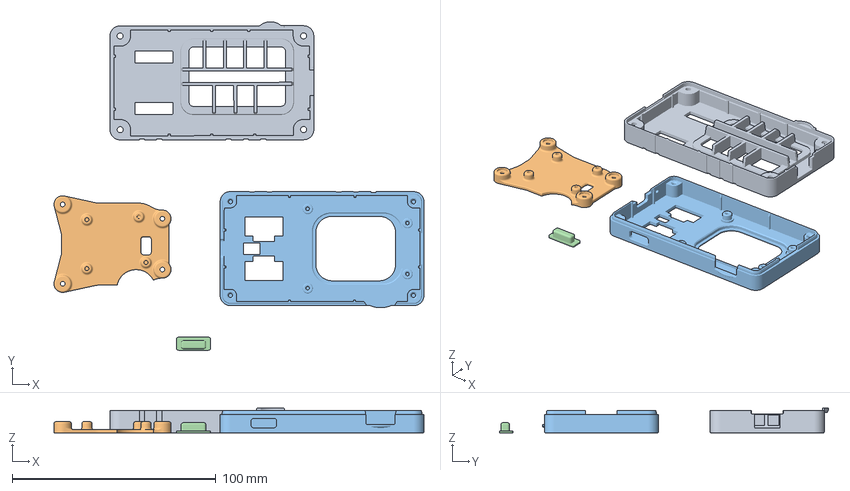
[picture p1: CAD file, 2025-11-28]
3_Product_housing/Bambu_Studio_XIAO_Debug_Mate.3mf
181.7 x 161.3 x 12.2 mm
332000047_Debugger_下壳;FDM,ABS,L100.1W58H12.2,黑色,去支撑毛刺.stp
332000045_Debugger_屏幕固定块;FDM,ABS,L57.5W47.5H6.4,黑色,去支撑毛刺.stp
332000046_Debugger_上壳;FDM,ABS,L100.1W57H11,黑色,去支撑毛刺.stp
332000044_Debugger_按键帽;FDM,ABS,L16.8W6.4H5,绿色,去支撑毛刺.stp

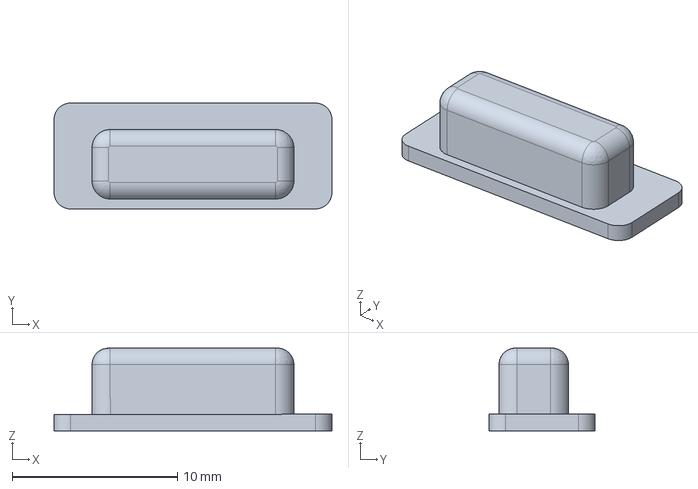
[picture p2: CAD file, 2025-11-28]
3_Product_housing/Debugger Keycap; FDM, ABS, L16.8W6.4H5, Green, Support-Removed and Deburred.stp
16.8 x 6.40 x 5.01 mm

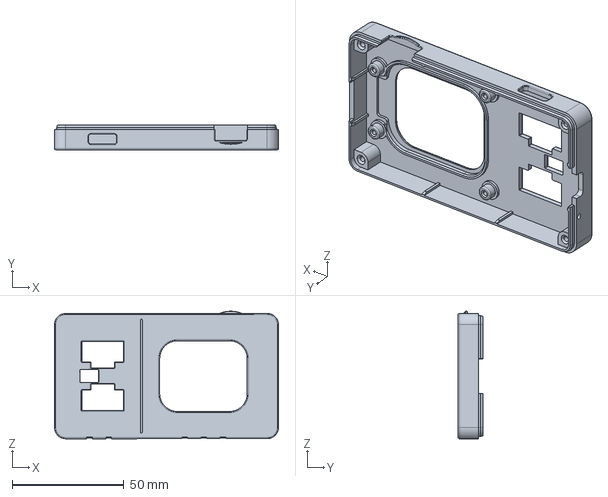
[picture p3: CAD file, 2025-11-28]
3_Product_housing/Debugger Upper Housing; FDM, ABS, L100 x W57 x H11 mm, Black, Remove Supports and Deburr.stp
100.1 x 11.0 x 57.0 mm

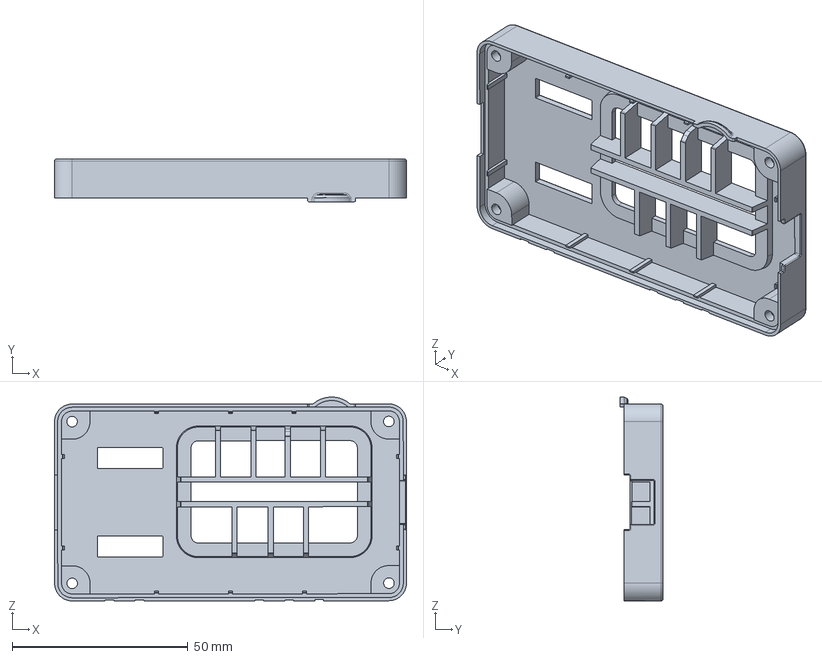
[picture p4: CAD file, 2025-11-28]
3_Product_housing/Debugger Lower Housing; FDM, ABS, L100 x W58 x H12.2, Black, Remove Supports and Deburr.stp
100.1 x 12.2 x 58.0 mm

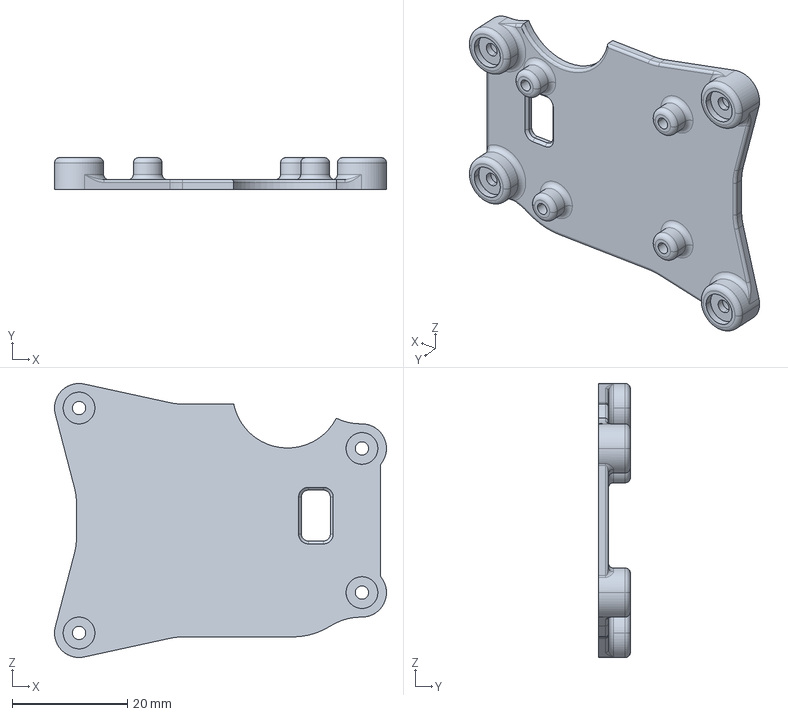
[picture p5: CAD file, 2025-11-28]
3_Product_housing/Debugger Screen Mounting Block; FDM, ABS, L57.5W47.5H6.4, Black, Deburred.stp
57.5 x 5.50 x 47.5 mm

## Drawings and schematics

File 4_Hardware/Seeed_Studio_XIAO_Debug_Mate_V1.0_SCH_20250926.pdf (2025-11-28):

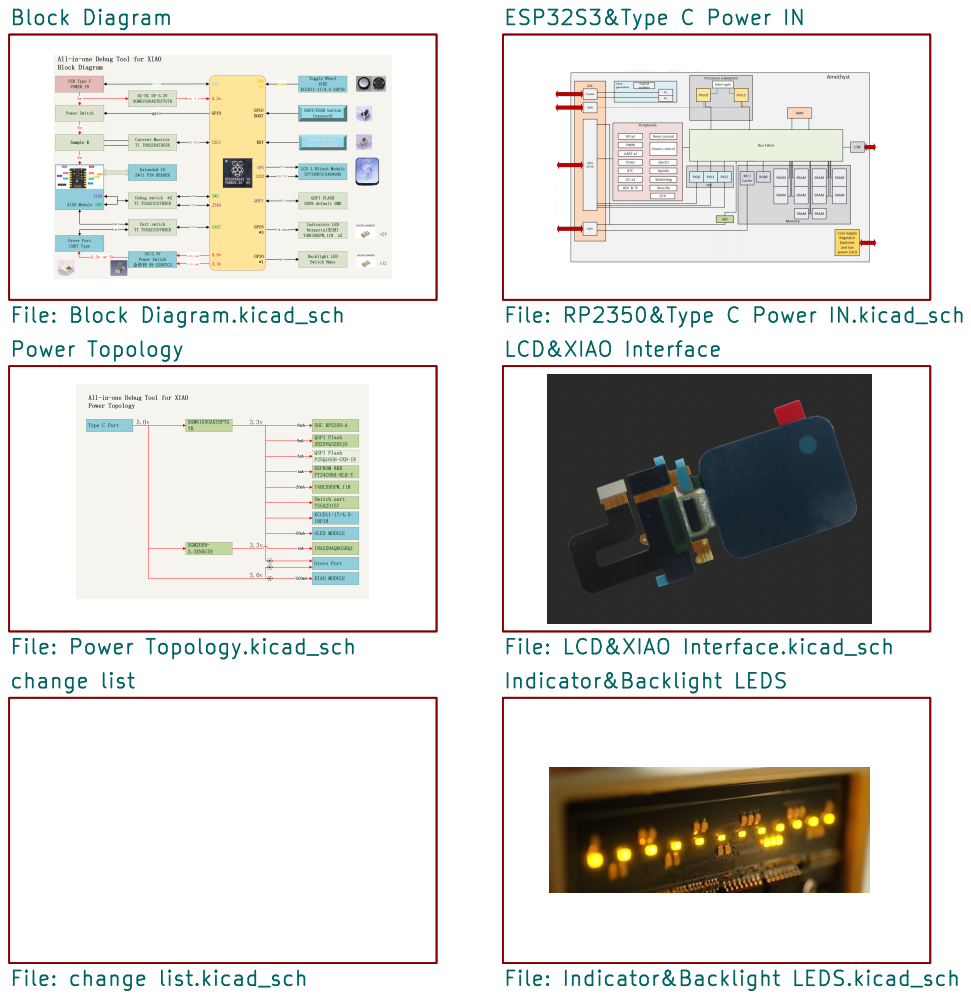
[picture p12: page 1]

Block Diagram
change list File: change list.kicad_sch Power Topology File: Power Topology.kicad_sch

LCD&XIAO Interface File: LCD&XIAO Interface.kicad_sch

Id: 1/7 Title: Debugger for Seeed Studio XIAO

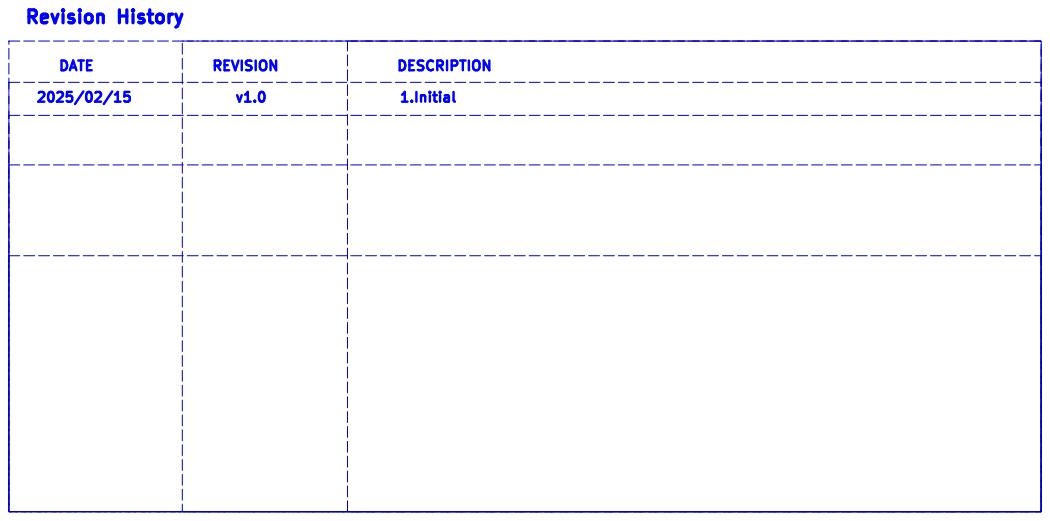
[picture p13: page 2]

Id: 2/7 Title: Debugger for Seeed Studio XIAO

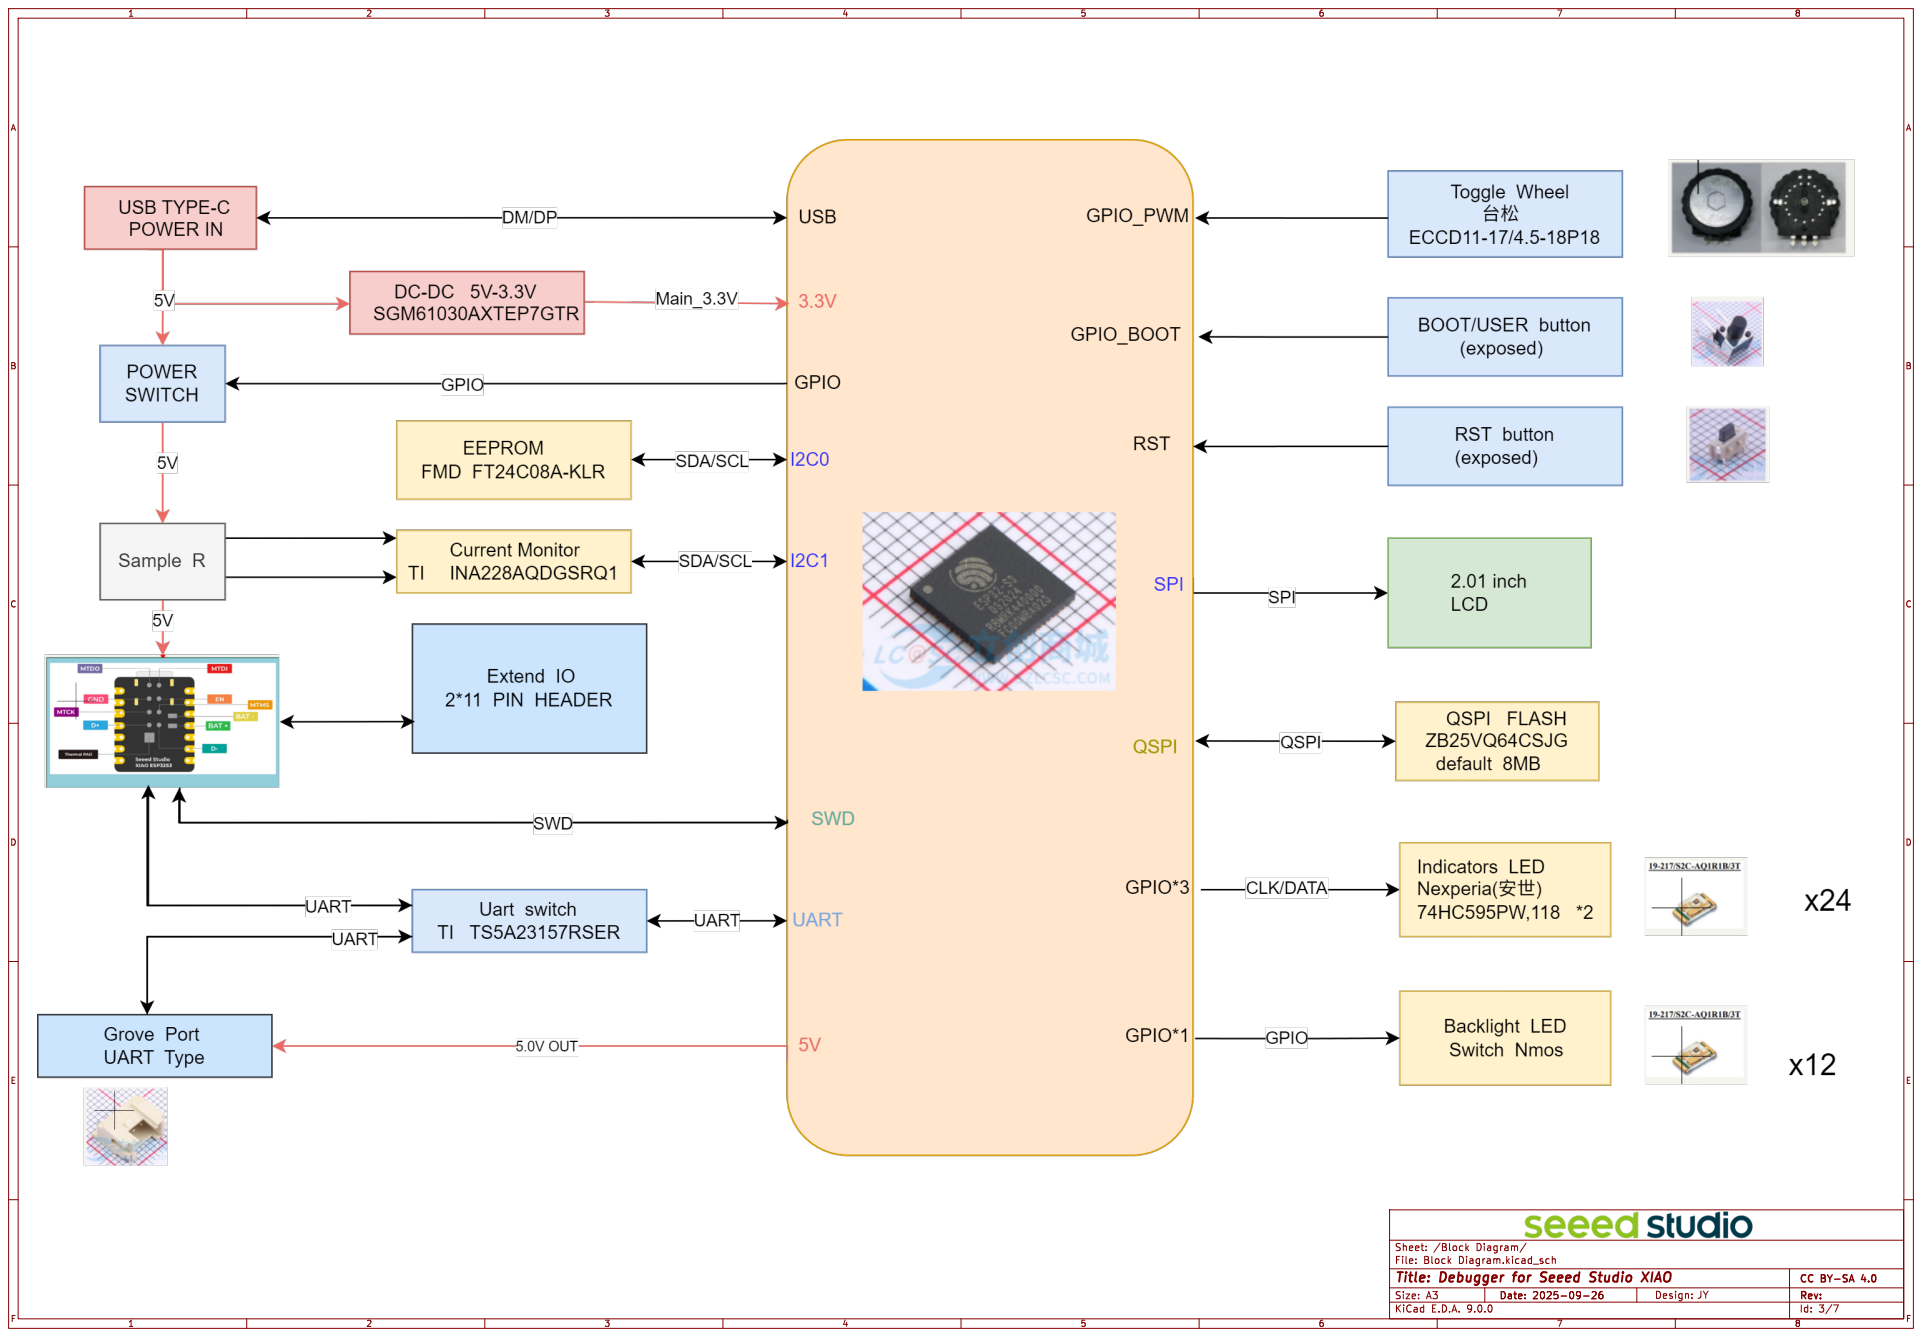
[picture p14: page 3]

Id: 3/7 Title: Debugger for Seeed Studio XIAO

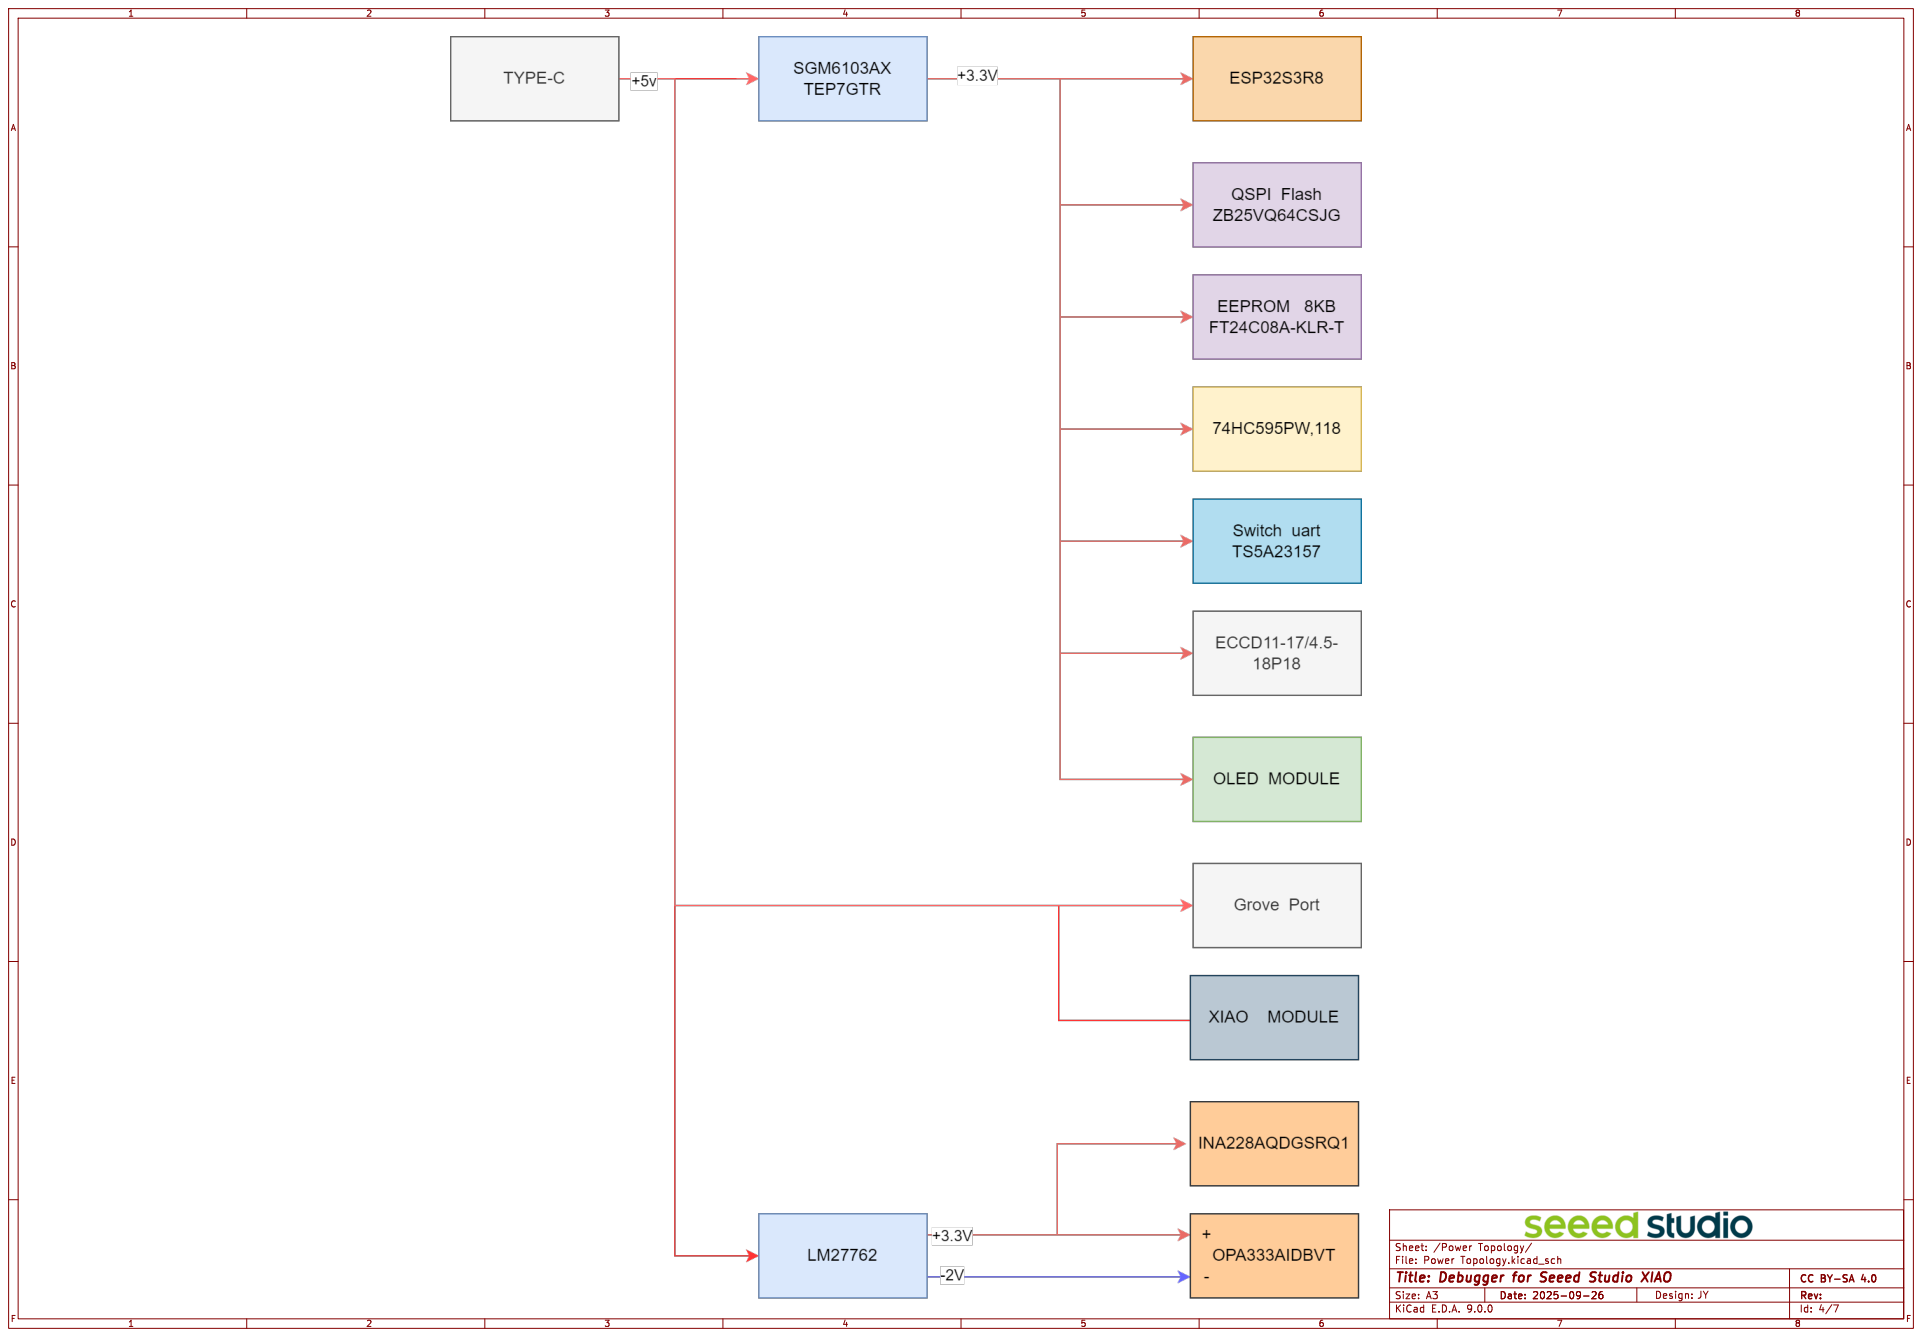
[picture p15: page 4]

Id: 4/7 Title: Debugger for Seeed Studio XIAO

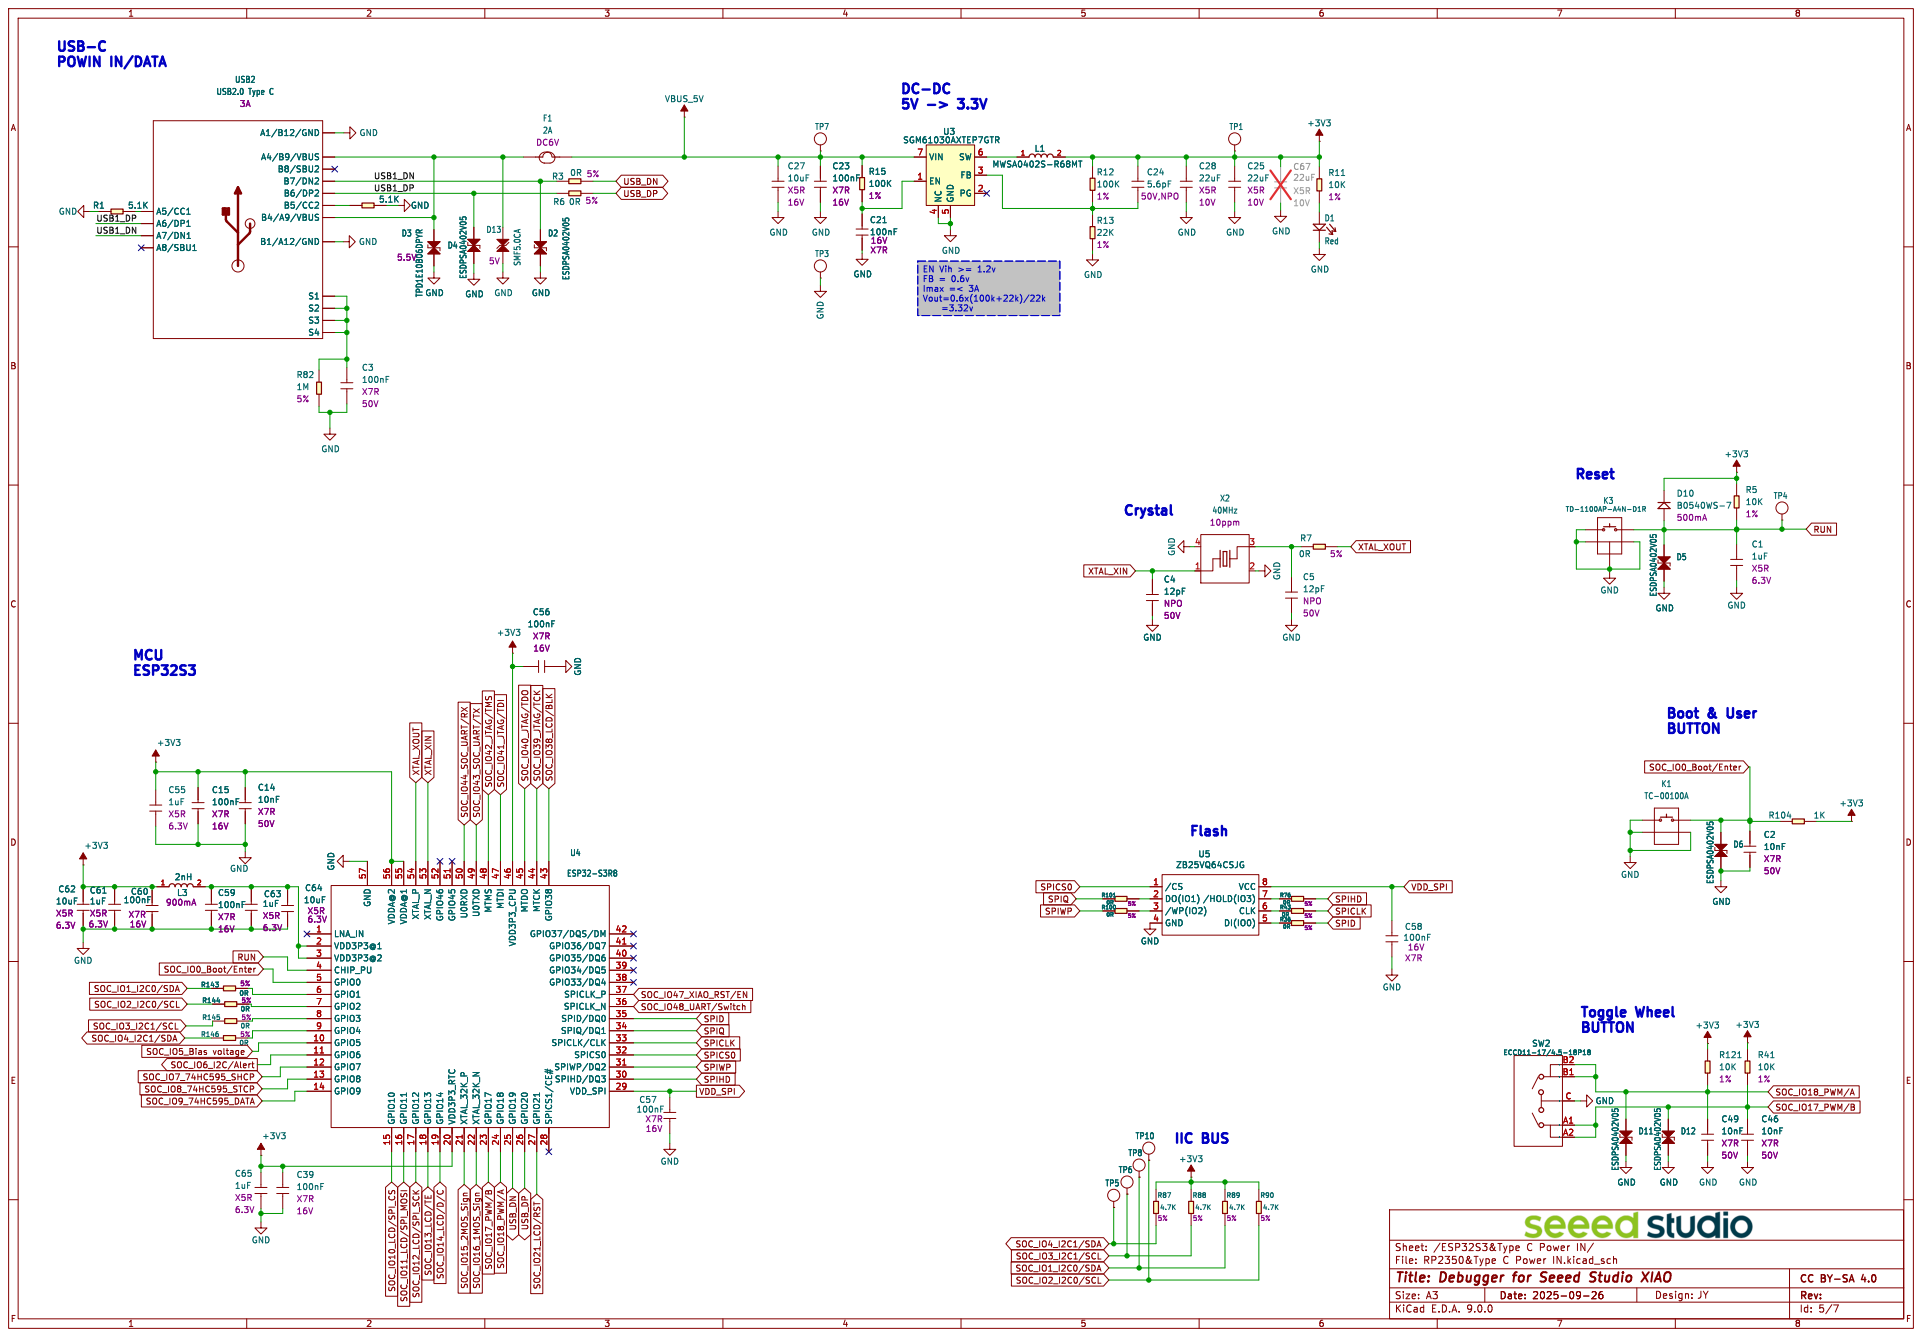
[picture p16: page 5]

Id: 5/7 Title: Debugger for Seeed Studio XIAO

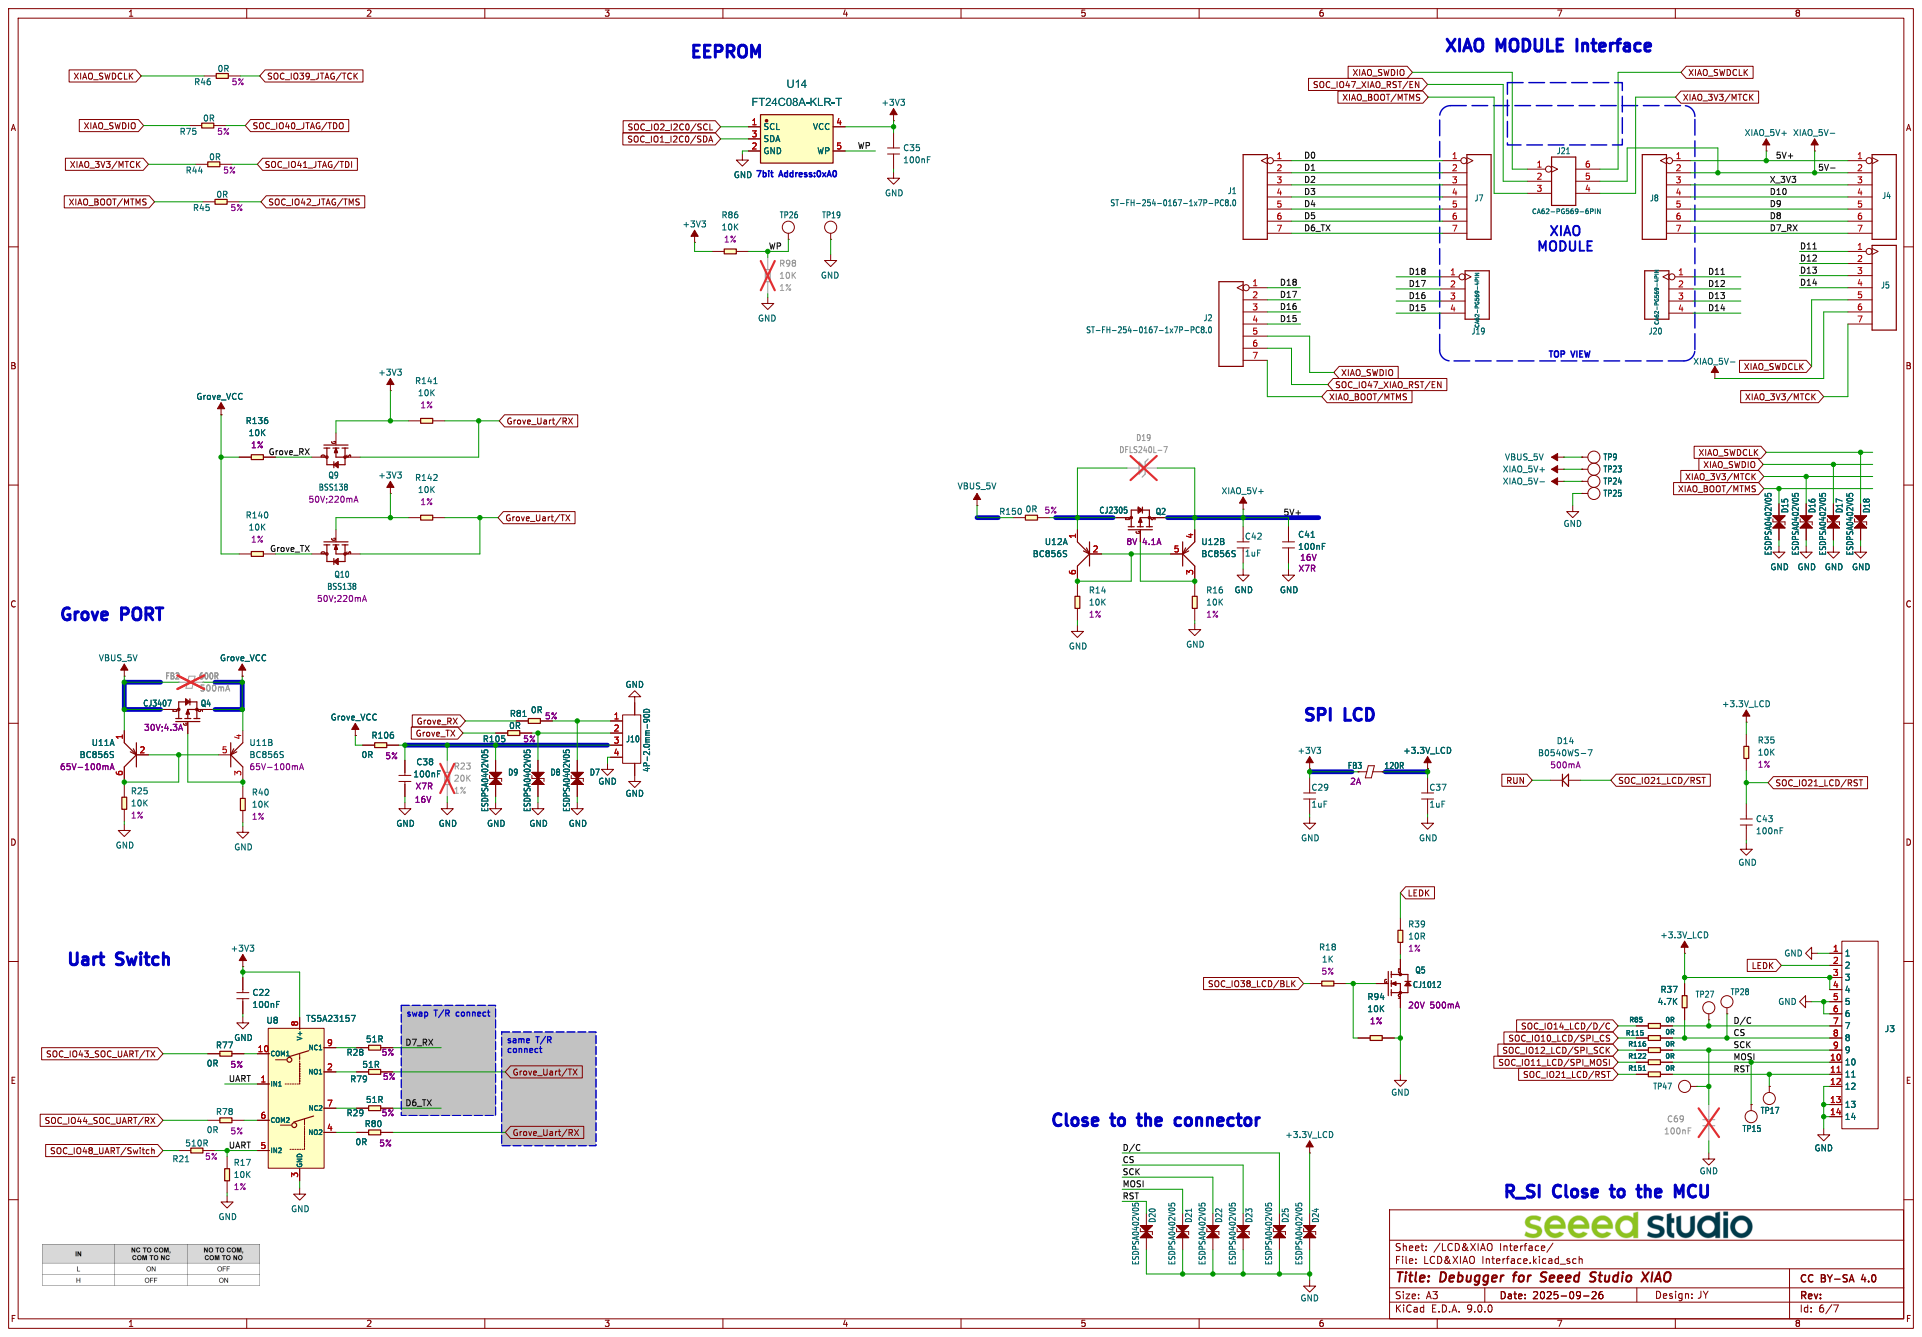
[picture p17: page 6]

R_SI Close to the MCU

Id: 6/7 Title: Debugger for Seeed Studio XIAO

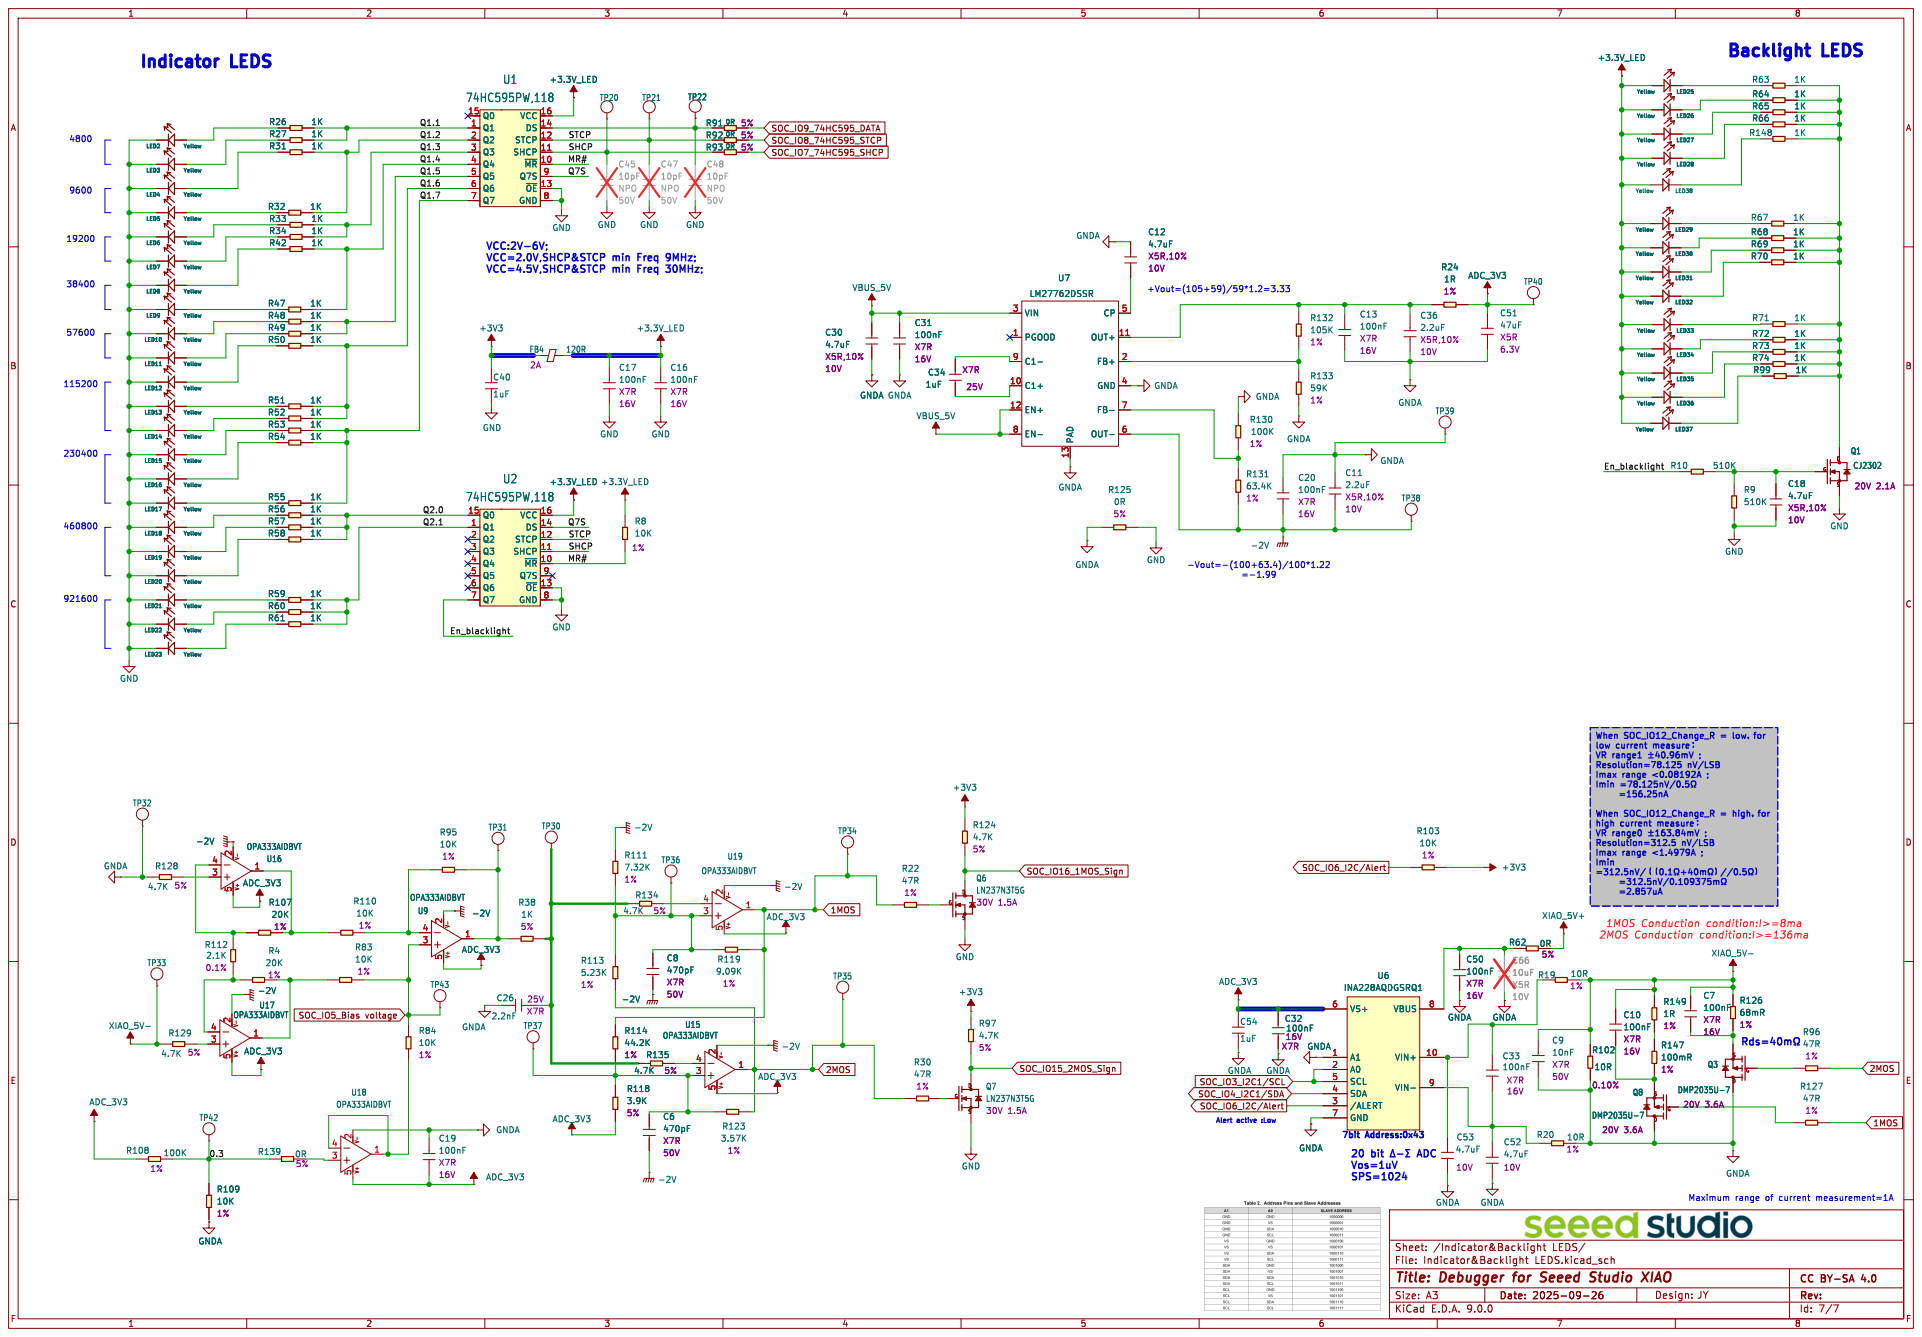
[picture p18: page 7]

Maximum range of current measurement=1A

Id: 7/7 Title: Debugger for Seeed Studio XIAO

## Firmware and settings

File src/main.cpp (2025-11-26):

#include "FreeRTOS.h"
#include "task.h"
#include "StateMachine.h"
#include "StateManager.h"
#include "MenuStates.h"
#include "InputTask.h"
#include "DisplayContext.h"
#include "ErrorState.h"
#include "FunctionUartState.h"
#include "FunctionBaudState.h"
#include "FunctionPowerState.h"

#include "DapLink.h"
#include "Global.h"
#include "Tool.h"
#include "LvglStyle.h"
#include "frame.h"

#include <Adafruit_INA228.h>

#define DRAW_BUF_SIZE (TFT_HOR_RES * TFT_VER_RES / 10 * (LV_COLOR_DEPTH / 8))
uint32_t draw_buf[DRAW_BUF_SIZE / 4];

// Create display context
DisplayContext displayContext;

// Create state machine instance
StateMachine stateMachine;

// Create input task instance
InputTask inputTask;

Adafruit_INA228 ina228;

// Error handler callback
void appErrorHandler(int errorCode, const char* errorMsg) {
    // Log error (optionally send via UART)
}

static uint32_t my_tick(void) {
    return millis();
}

void initSerial() {
    COMSerial.begin(FunctionBaudState::m_baudRate);

    pinMode(UART_SWITCH, OUTPUT);
    digitalWrite(UART_SWITCH, LOW);
}

void initLED() {
    pinMode(LED_DATA, OUTPUT);
    pinMode(LED_CLOCK, OUTPUT);
    pinMode(LED_LATCH, OUTPUT);

    displayContext.updateBaudLED(1, true);
}

void animBootCompleted(lv_anim_t* anim) {
    stateMachine.setBootCompleted();
}

void initAnimBoot(lv_obj_t* scr) {
    lv_obj_t* animimg = lv_animimg_create(scr);
    lv_obj_center(animimg);
    lv_animimg_set_src(animimg, (const void **) anim_boot_imgs, BOOT_FRAME_SIZE);
    lv_animimg_set_duration(animimg, 4850);
    lv_animimg_set_repeat_count(animimg, 1);
    lv_animimg_set_completed_cb(animimg, animBootCompleted);
    lv_animimg_start(animimg);
}

static void bootTaskFunc(void* params) {
    initAnimBoot(lv_scr_act());

    while (true) {
        if (stateMachine.getBootCompleted()) {
            vTaskDelete(NULL);
        }

        lv_timer_handler();
        vTaskDelay(30);
    }
}

void initLVGL() {
    lv_init();

    lv_tick_set_cb(my_tick);

    lv_display_t* disp;
    disp = lv_tft_espi_create(TFT_HOR_RES, TFT_VER_RES, draw_buf, sizeof(draw_buf));
    lv_display_set_rotation(disp, TFT_ROTATION);

    static lv_style_t style_screen;
    lv_style_init(&style_screen);
    lv_style_set_bg_color(&style_screen, lv_color_hex(0x000000));

    lv_obj_add_style(lv_scr_act(), &style_screen, 0);

    xTaskCreate(
        bootTaskFunc,
        "boot Task Func",
        8192,
        nullptr,
        1,
        nullptr
    );

    while (true) {
        if (stateMachine.getBootCompleted()) {
            break;
        }
        delay(100);
    }
}

void initINA228() {
    pinMode(MOS1_PIN, INPUT);
    pinMode(MOS2_PIN, INPUT);

    ina228 = Adafruit_INA228();

    Wire.setPins(INA_I2C_SDA, INA_I2C_SCL);
    Wire.setClock(INA_I2C_FREQUENCY);

    if (!ina228.begin(INA_I2C_ADDR)) {
        ShowSerial.println("Couldn't find INA228 chip");
        return;
    }

    // set shunt resistance and max current
    ina228.setShunt(0.068, 1.0);
    ina228.setAveragingCount(INA228_COUNT_16);

    // set the time over which to measure the current and bus voltage
    ina228.setVoltageConversionTime(INA228_TIME_150_us);
    ina228.setCurrentConversionTime(INA228_TIME_280_us);
}

void setup() {
    // Hardware initialization
    initSerial();
    initLED();
    initLVGL();
    displayContext.setBrightness(70);
    initStyle();
    initDapLink();
    ShowSerial.begin(FunctionBaudState::m_baudRate);
    initINA228();
    initValueFromEEPROM();
    pinMode(BOOT_BTN, INPUT_PULLUP);
    pinMode(ENCODER_PINA, INPUT);
    pinMode(ENCODER_PINB, INPUT);
    ShowSerial.setDebugOutput(true);

    // Register states
    StateManager* stateManager = StateManager::getInstance();

    // Create and register main menu state
    MainMenuState* mainMenu = new MainMenuState();
    FunctionUartState* uartState = new FunctionUartState();
    FunctionBaudState* baudState = new FunctionBaudState();
    FunctionPowerState* powerState = new FunctionPowerState();

    // Add menu items
    mainMenu->addMenuItem("Function Uart", FunctionUartState::ID);
    mainMenu->addMenuItem("Function Power", FunctionPowerState::ID);
    stateManager->registerState(mainMenu);

    // Register functional states
    stateManager->registerState(uartState);
    stateManager->registerState(baudState);
    stateManager->registerState(powerState);
    // TODO: Register other functional states...

    // Create error state
    ErrorState* errorState = new ErrorState();
    stateManager->registerState(errorState);

    // Set error handler
    stateMachine.setErrorHandler(appErrorHandler);

    displayContext.setINA228(&ina228);

    // Set display context
    stateMachine.setDisplayContext(&displayContext);

    // Initialize state machine: main menu as initial state, error state for exception handling
    if (!stateMachine.init(mainMenu, errorState)) {
    // Handle initialization failure
        while(1) {
            ShowSerial.printf("StateMachine init failed here\n");
            delay(100);
        }
    }

    inputTask.setStateMachine(&stateMachine);

    // Start state machine task
    if (!stateMachine.start(1)) {
    // Handle start failure
        while(1) {
            ShowSerial.printf("StateMachine start failed here\n");
            delay(100);
        }
    }

    // Start input task
    if (!inputTask.start(2)) {
    // Handle input task start failure
        stateMachine.stop();
        while(1) {
            ShowSerial.printf("InputTask start failed here\n");
            delay(100);
        }
    }

    ShowSerial.printf("All settings are successful\n");
}

void loop()
{
}

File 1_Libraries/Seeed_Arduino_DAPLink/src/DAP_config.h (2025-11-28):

/* CMSIS-DAP ported to run on the Arduino Micro
 * Copyright (C) 2016 Phillip Pearson <pp@myelin.co.nz>
 *
 * CMSIS-DAP Interface Firmware
 * Copyright (c) 2009-2013 ARM Limited
 *
 * Licensed under the Apache License, Version 2.0 (the "License");
 * you may not use this file except in compliance with the License.
 * You may obtain a copy of the License at
 *
 *     http://www.apache.org/licenses/LICENSE-2.0
 *
 * Unless required by applicable law or agreed to in writing, software
 * distributed under the License is distributed on an "AS IS" BASIS,
 * WITHOUT WARRANTIES OR CONDITIONS OF ANY KIND, either express or implied.
 * See the License for the specific language governing permissions and
 * limitations under the License.
 */

// #ifdef TEENSYDUINO
// #define TEENSY_RAWHID
// #include "usb_desc.h"
// #else
// #define HIDPROJECT_RAWHID
// #include "HID-Project.h"
// #endif


#ifndef __DAP_CONFIG_H__
#define __DAP_CONFIG_H__

#if !defined(USE_TINYUSB)
#if defined(ARDUINO_ARCH_ESP32)
#include "Adafruit_TinyUSB.h"
#else
#error TinyUSB is not selected, please select it in "Tools->Menu->USB Stack"
#endif
#else
#include "Adafruit_TinyUSB.h"
#endif


#define __forceinline __attribute__((always_inline))
#define __weak
#define OS_TID int
#define __task
#define U64 uint64_t
#define os_dly_wait delayMicroseconds

#define DAP_VENDOR "Seeed"
#define DAP_PRODUCT "Seeed CMSIS-DAP"
#define DAP_SER_NUM "1234"

//**************************************************************************************************
/**
\defgroup DAP_Config_Debug_gr CMSIS-DAP Debug Unit Information
\ingroup DAP_ConfigIO_gr
@{
Provides definitions about:
 - Definition of Cortex-M processor parameters used in CMSIS-DAP Debug Unit.
 - Debug Unit communication packet size.
 - Debug Access Port communication mode (JTAG or SWD).
 - Optional information about a connected Target Device (for Evaluation Boards).
*/

#include <Arduino.h>                             // Debug Unit Cortex-M Processor Header File
#include "usb_desc.h"
/// Processor Clock of the Cortex-M MCU used in the Debug Unit.
/// This value is used to calculate the SWD/JTAG clock speed.
#define CPU_CLOCK               F_CPU        ///< Specifies the CPU Clock in Hz

/// Number of processor cycles for I/O Port write operations.
/// This value is used to calculate the SWD/JTAG clock speed that is generated with I/O
/// Port write operations in the Debug Unit by a Cortex-M MCU. Most Cortex-M processors
/// requrie 2 processor cycles for a I/O Port Write operation.  If the Debug Unit uses
/// a Cortex-M0+ processor with high-speed peripheral I/O only 1 processor cycle might be
/// requrired.
#define IO_PORT_WRITE_CYCLES    1               ///< I/O Cycles: 2=default, 1=Cortex-M0+ fast I/0

#if !defined(DAP_SERIAL_LOG)
#define DAP_SERIAL_LOG          1
#endif

/// Indicate that Serial Wire Debug (SWD) communication mode is available at the Debug Access Port.
/// This information is returned by the command \ref DAP_Info as part of <b>Capabilities</b>.
#if !defined(DAP_SWD)
#define DAP_SWD                 1               ///< SWD Mode:  1 = available, 0 = not available
#endif

/// Indicate that JTAG communication mode is available at the Debug Port.
/// This information is returned by the command \ref DAP_Info as part of <b>Capabilities</b>.
#if !defined(DAP_JTAG)
#define DAP_JTAG                1               ///< JTAG Mode: 1 = available, 0 = not available.
#endif

/// Configure maximum number of JTAG devices on the scan chain connected to the Debug Access Port.
/// This setting impacts the RAM requirements of the Debug Unit. Valid range is 1 .. 255.
#define DAP_JTAG_DEV_CNT        4               ///< Maximum number of JTAG devices on scan chain

/// Default communication mode on the Debug Access Port.
/// Used for the command \ref DAP_Connect when Port Default mode is selected.
#define DAP_DEFAULT_PORT        1               ///< Default JTAG/SWJ Port Mode: 1 = SWD, 2 = JTAG.

/// Default communication speed on the Debug Access Port for SWD and JTAG mode.
/// Used to initialize the default SWD/JTAG clock frequency.
/// The command \ref DAP_SWJ_Clock can be used to overwrite this default setting.
#define DAP_DEFAULT_SWJ_CLOCK   5000000         ///< Default SWD/JTAG clock frequency in Hz.

/// Maximum Package Size for Command and Response data.
/// This configuration settings is used to optimized the communication performance with the
/// debugger and depends on the USB peripheral. Change setting to 1024 for High-Speed USB.
#define DAP_PACKET_SIZE         RAWHID_RX_SIZE              ///< USB: 64 = Full-Speed, 1024 = High-Speed.
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

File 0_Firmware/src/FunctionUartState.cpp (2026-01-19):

#include "Global.h"
#include "MenuStates.h"
#include "FunctionUartState.h"

FunctionUartState::FunctionUartState()
    : FunctionState("FunctionUartState"),
      m_isUartInfoDisplay(false),
      m_currentSelection(0),
      m_uartType(UartType::UART_TYPE_XIAO),
      m_uartStateUI(),
      m_uartTask(nullptr),
      m_lastRxTime(0),
      m_lastTxTime(0)
{
    m_rxQueue = xQueueCreate(UART_DATA_SIZE, sizeof(char));
    m_txQueue = xQueueCreate(UART_DATA_SIZE, sizeof(char));

    xTaskCreate(
        uartTaskFunc,
        "UartTask",
        20480,
        this,
        2,
        &m_uartTask
    );

    vTaskSuspend(m_uartTask);
}

void FunctionUartState::uartTaskFunc(void* params) {
    FunctionUartState* uartState = static_cast<FunctionUartState*> (params);
    const int BUFFER_SIZE = 256;
    char buffer[BUFFER_SIZE];

    while (true) {
        bool hasData = false;

        // RX, From XIAO to Debugger
        int rxAvail = COMSerial.available();
        if (rxAvail > 0) {
            uartState->m_lastRxTime = millis();
            int count = (rxAvail < BUFFER_SIZE) ? rxAvail : BUFFER_SIZE;
            int n = COMSerial.readBytes(buffer, count);

            if (uartState->m_isUartInfoDisplay) {
                for (int i = 0; i < n; i++) {
                    xQueueSendToBack(uartState->m_rxQueue, &buffer[i], 0);
                }
            } else {
                ShowSerial.write(buffer, n);
            }
            hasData = true;
        }

        // TX, From PC to XIAO
        int txAvail = ShowSerial.available();
        if (txAvail > 0) {
            uartState->m_lastTxTime = millis();
            int count = (txAvail < BUFFER_SIZE) ? txAvail : BUFFER_SIZE;
            int n = ShowSerial.readBytes(buffer, count);

            COMSerial.write(buffer, n);
            if (uartState->m_isUartInfoDisplay) {
                for (int i = 0; i < n; i++) {
                    xQueueSendToBack(uartState->m_txQueue, &buffer[i], 0);
                }
            }
            hasData = true;
        }

        if (hasData) {
            vTaskDelay(pdMS_TO_TICKS(3));
        } else {
            vTaskDelay(pdMS_TO_TICKS(30));
        }
    }
}

void FunctionUartState::createOptionBarUI() {
    // UART Type
    m_uartStateUI.UartTypeBg = lv_obj_create(m_uartStateUI.Screen);
    lv_obj_set_size(m_uartStateUI.UartTypeBg, 130, 42);
    lv_obj_set_pos(m_uartStateUI.UartTypeBg, 12 + 12, 15);
    lv_obj_add_style(m_uartStateUI.UartTypeBg, &style_nofocus_uart_bg, 0);

    lv_obj_t* label = lv_label_create(m_uartStateUI.UartTypeBg);
    lv_obj_set_pos(label, 22, 10);
    lv_label_set_text(label, "UART:");
    lv_obj_set_style_text_color(label, lv_color_hex(0xA6ACAF), LV_PART_MAIN);
    lv_obj_add_style(label, &style_font_14, 0);

    m_uartStateUI.UartTypeLabel = lv_label_create(m_uartStateUI.UartTypeBg);
    lv_label_set_text_fmt(m_uartStateUI.UartTypeLabel, "%s", (m_uartType == UartType::UART_TYPE_XIAO)? "XIAO" : "Grove");
    lv_obj_set_pos(m_uartStateUI.UartTypeLabel, 12 + 12 + 50, 10);
    lv_obj_set_style_text_color(m_uartStateUI.UartTypeLabel, lv_color_hex(0xFFFFFF), LV_PART_MAIN);
    lv_obj_add_style(m_uartStateUI.UartTypeLabel, &style_font_14, 0);

    // BaudRate
    m_uartStateUI.UartBaudBg = lv_obj_create(m_uartStateUI.Screen);
    lv_obj_set_size(m_uartStateUI.UartBaudBg, 130, 42);
    lv_obj_set_pos(m_uartStateUI.UartBaudBg, 154 + 12, 15);
    lv_obj_add_style(m_uartStateUI.UartBaudBg, &style_nofocus_uart_bg, 0);

    m_uartStateUI.UartBaudLabel = lv_label_create(m_uartStateUI.UartBaudBg);
    lv_label_set_text_fmt(m_uartStateUI.UartBaudLabel, "%d", FunctionBaudState::m_baudRate);
    lv_obj_align(m_uartStateUI.UartBaudLabel, LV_ALIGN_TOP_MID, 0, 5);
    lv_obj_set_style_text_color(m_uartStateUI.UartBaudLabel, lv_color_hex(0xFFFFFF), LV_PART_MAIN);
    lv_obj_add_style(m_uartStateUI.UartBaudLabel, &style_font_14, 0);

    static lv_point_precise_t p[] = {{0, 5}, {45, 5}, {45, 0}, {45, 5}, {90, 5}};
    m_uartStateUI.UartBaudLine = lv_line_create(m_uartStateUI.UartBaudBg);
    lv_obj_add_style(m_uartStateUI.UartBaudLine, &style_uart_line, 0);
    lv_line_set_points(m_uartStateUI.UartBaudLine, p, 5);
    lv_obj_align(m_uartStateUI.UartBaudLine, LV_ALIGN_TOP_MID, 0, 22);
}

void FunctionUartState::createLedUI() {
    // RX LED Group
    m_uartStateUI.UartRxLEDGroup = lv_obj_create(m_uartStateUI.Screen);
    lv_obj_set_size(m_uartStateUI.UartRxLEDGroup, 194, 37);
    lv_obj_set_pos(m_uartStateUI.UartRxLEDGroup, 12 + 51, 88);
    lv_obj_add_style(m_uartStateUI.UartRxLEDGroup, &style_screen, 0);

    lv_obj_t* label = lv_label_create(m_uartStateUI.UartRxLEDGroup);
    lv_label_set_text(label, "RX");
    lv_obj_align(label, LV_ALIGN_CENTER, 0, 0);
    lv_obj_set_style_text_color(label, lv_color_hex(0xDDE62), LV_PART_MAIN);
    lv_obj_add_style(label, &style_font_28, 0);

    // TX LED Group
    m_uartStateUI.UartTxLEDGroup = lv_obj_create(m_uartStateUI.Screen);
    lv_obj_set_size(m_uartStateUI.UartTxLEDGroup, 194, 37);
    lv_obj_set_pos(m_uartStateUI.UartTxLEDGroup, 12 + 51, 155);
    lv_obj_add_style(m_uartStateUI.UartTxLEDGroup, &style_screen, 0);

    label = lv_label_create(m_uartStateUI.UartTxLEDGroup);
    lv_label_set_text(label, "TX");
    lv_obj_align(label, LV_ALIGN_CENTER, 0, 0);
    lv_obj_set_style_text_color(label, lv_color_hex(0x2FE6AC), LV_PART_MAIN);
    lv_obj_add_style(label, &style_font_28, 0);

    // LED List
    // Left Part, start from the middle to the left
    int xPos = 60;
    for (int i = 0; i < 5; i++) {
        // TX
        m_uartStateUI.UartRxLedLeftList[i] = lv_led_create(m_uartStateUI.UartRxLEDGroup);
        lv_obj_set_pos(m_uartStateUI.UartRxLedLeftList[i], xPos, 14 + i);
        lv_led_off(m_uartStateUI.UartRxLedLeftList[i]);
        lv_led_set_color(m_uartStateUI.UartRxLedLeftList[i], lv_color_hex(0xDDE62F));
        lv_obj_set_size(m_uartStateUI.UartRxLedLeftList[i], 10 - (i * 2), 10 - (i * 2));
        lv_obj_add_style(m_uartStateUI.UartRxLedLeftList[i], &style_led, 0);

        // RX
        m_uartStateUI.UartTxLedLeftList[i] = lv_led_create(m_uartStateUI.UartTxLEDGroup);
        lv_obj_set_pos(m_uartStateUI.UartTxLedLeftList[i], xPos, 14 + i);
        lv_led_off(m_uartStateUI.UartTxLedLeftList[i]);
        lv_led_set_color(m_uartStateUI.UartTxLedLeftList[i], lv_color_hex(0x2FE6AC));
        lv_obj_set_size(m_uartStateUI.UartTxLedLeftList[i], 10 - (i * 2), 10 - (i * 2));
        lv_obj_add_style(m_uartStateUI.UartTxLedLeftList[i], &style_led, 0);

        xPos -= 18 - (i * 2);
    }
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

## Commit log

2025-06-09 feat: update source code
    - implemente two display contents of the serial port interface
    - implemente three power consumption interfaces and optimized the logic
    of total power consumption
    - supports wheel switching options or interfaces, and uses buttons to
    confirm
    - supports serial port type and serial port baud rate switching, and
    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
2025-10-17 feat: Adding offset support for current compensation calculation to different mos mode.
2025-10-20 feat: Adjust the max measure volt of mos00 mode
2025-10-21 feat: expand voltage range
2025-10-21 feat: Make the current label red when it exceeds 1A.
2025-10-22 feat: Refactor initValueFromEEPROM to use I2C_eeprom library
2025-10-22 fix:Make EEPROM value not participate in clamping
2025-11-10 perf: add current compensation values for certain ranges. From Lesords.
2025-11-28 Organize all documents
    [100ask-openjtag.cfg, 8devices-lima.cfg, Bambu_Studio_XIAO_Debug_Mate.3mf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]
2026-01-19 feat: Optimize UART task for improved data handling and responsiveness
2026-01-19 fix: Fixed the issue where the flowing light fails after using batch processing.
    [FunctionUartState.cpp]
2026-07-13 feat: add POWER_DEBUG switch for power measurement logging

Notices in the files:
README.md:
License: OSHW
